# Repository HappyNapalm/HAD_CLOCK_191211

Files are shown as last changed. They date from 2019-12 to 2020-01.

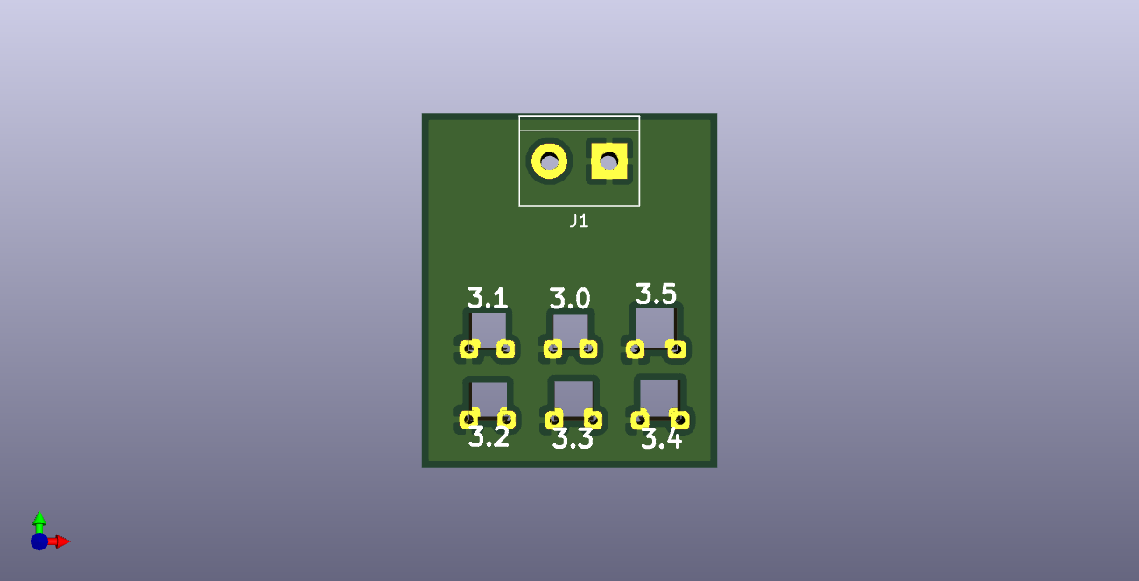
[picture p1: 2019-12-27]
renders/01_LED_test/rear.png

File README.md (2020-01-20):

# HAD_CLOCK_191211 #
Clock for HAD Contest

## TODO ##
* Final verification of footprints. Last time!
* Sort out transformer
* Design an enclosure
* Add buttons to program the time (Research cap touch)
* Convert Mouser Project into csv

~~Microcontroller Corrections to PIC18F45K20~~

~~Consider making a version for the LPC804 as well as the PIC~~

~~Consider making multiple sheets for the schematic~~

~~Redo the outline in 4 x 15 pattern instead of a 3 x 20 pattern~~

## Parts to Select ##
* Transformer
* Diodes
* Resist0r 0603 100 ohm for 20 mAs at 3v3. 72 resistors

~~Shift Register (Affects resistor size)~~

~~Full rectifier~~

## Brief License ##
* Non-comericial
* Unlimited remakes for personal use
* Cite this project as source for any re-mixes

### Online Resources ###
https://www.pcbway.com/pcb_prototype/What_are_Plated_Half_Holes_Castellated_Holes_.html

### KiCAD Renders ###

Front | Back
:-------:|:------:
![Clock Front] (https://github.com/HappyNapalm/HAD_CLOCK_191211/blob/pic18/front.png)  |  ![Clock Rear] (https://github.com/HappyNapalm/HAD_CLOCK_191211/blob/pic18/rear.png)

![LED Test Front] (../renders/01_LED_test/front.png)

![LED Test Rear] (../renders/01_LED_test/rear.png)

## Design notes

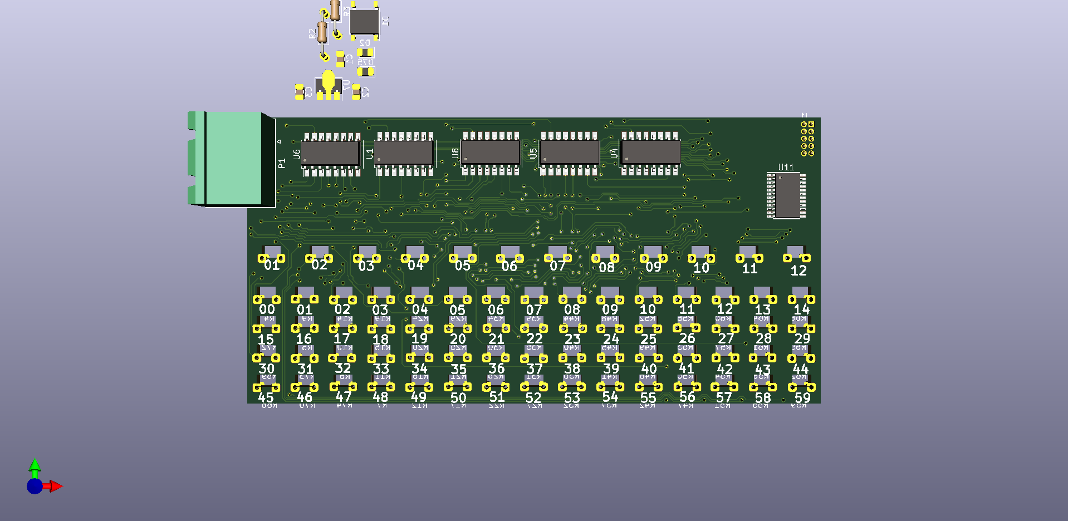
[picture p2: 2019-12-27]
front.png

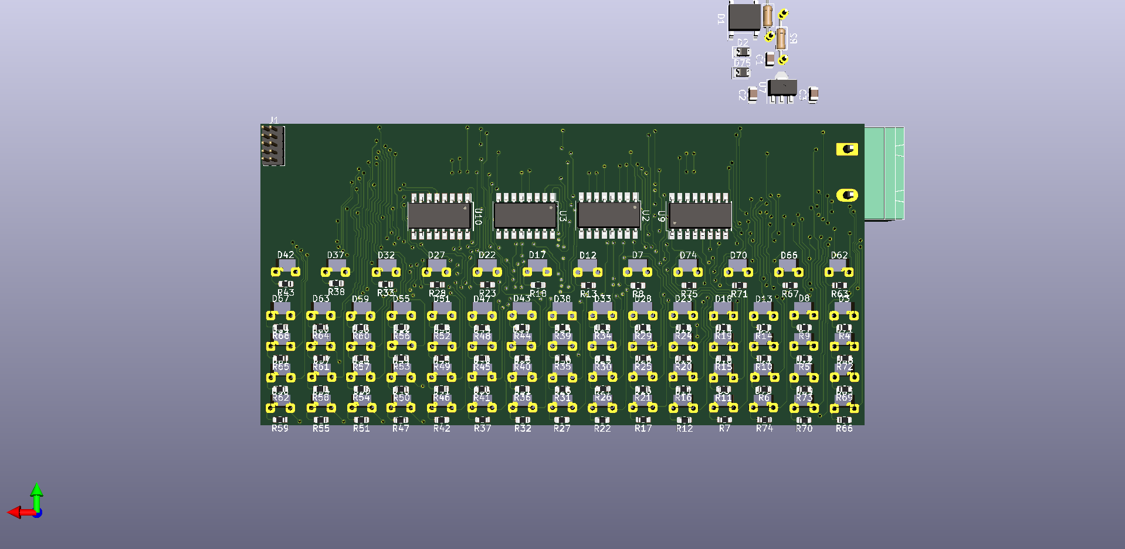
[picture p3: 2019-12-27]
rear.png

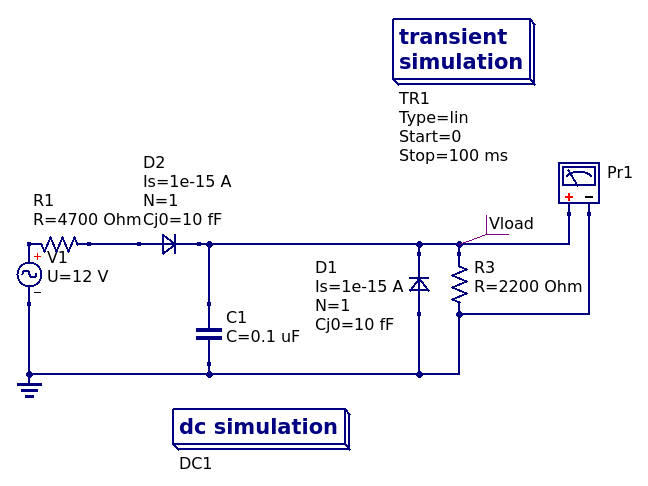
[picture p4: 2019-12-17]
Qucs Sims/sim_circuit.png

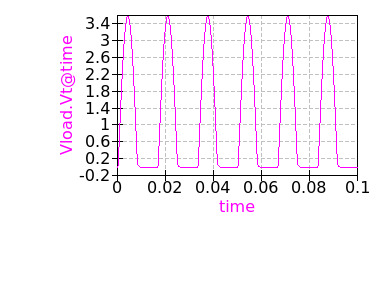
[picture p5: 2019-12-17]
Qucs Sims/sim_signal.png

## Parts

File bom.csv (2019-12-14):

Mouser PN | Description | Package | Quantity
771-NPIC6C596ADJ | Counter Shift Registers Power logic 8-bit. 596 Open Drain shift register | SO-16 | 9

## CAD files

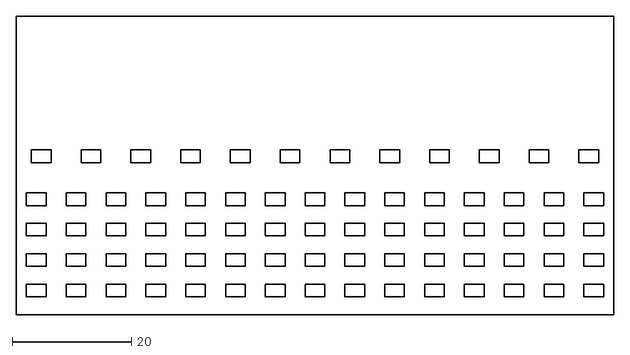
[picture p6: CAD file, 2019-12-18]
FreeCAD/clock_outline.dxf
100.0 x 50.0

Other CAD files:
FreeCAD/LED_hole_test.FCStd
FreeCAD/Clock_idea_outline.FCStd
FreeCAD/LED_hole_test.dxf

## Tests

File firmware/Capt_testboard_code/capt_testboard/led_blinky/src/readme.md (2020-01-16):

## Overview
-----------------------------------------------------------------------------------------
The LED Blinky demo application provides a sanity check for the new SDK build environments 
and board bring up. The LED Blinky demo uses the systick interrupt to realize the function 
of timing delay. The demo takes turns to shine the LED. The purpose of this demo is to 
provide a simple project for debugging and further development.

## Functional Description
-----------------------------------------------------------------------------------------
The LED Blinky demo mainly is to bring up the new SDK build environments on the board.
This demo will initialize the pin configuration, then configure System Tick to generate 
1ms interrupt. When 1000 interrupts occur(1s), the pin output of LED is toggled. We can 
see that LED is blinking on the board.

## Toolchain Supported
---------------------
- IAR embedded Workbench 8.22.1
- Keil MDK 5.24a
- MCUXpresso10.2.0

## Hardware Requirements
------------------------
- Mini/micro USB cable
- LPCXpresso804 board
- Personal Computer

## Board Settings
------------------------
No special settings are required.

## Run the Demo
------------------------
1. Connect a micro USB cable between the PC host and the CMSIS DAP port(CN2 on the board).

2. Choose an IDE, building the project and download the program to the target board.
   More information about how to compile and program the project can refer to the 

   [Getting Started with MCUXpresso SDK](../../../../docs/Getting Started with MCUXpresso SDK.pdf).

3. Launch the debugger in your IDE to begin running the demo.

## Expected Result
------------------------
When the demo runs successfully, you will find the LED is blinking.

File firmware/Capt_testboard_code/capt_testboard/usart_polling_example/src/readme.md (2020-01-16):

## Overview
-----------
This example demonstrates configuration and use of the USART module in polling-driven 
asynchronous mode on communication with a terminal emulator calling the USART functional
APIs. USART will echo back every 8 characters to terminal emulator.

**Transactional API and Functional API**

- Low level functional APIs provide common peripheral functionality, abstracting the 
  hardware peripheral register access into a set of state less basic functional operations.
  These APIs primarily focus on the control, configuration, and function of basic 
  peripheral operations. 

- Transactional APIs provide a quick method for customers to utilize higher-level 
  functionality of the peripherals. The transactional APIs utilize interrupts and perform 
  asynchronous operations without user intervention. Transactional APIs operate on high-
  level logic that requires data storage for internal operation context handling. However,
  the peripheral drivers do not allocate this memory space. Rather, the user passes in the
  memory to the driver for internal driver operation. 

- All driver examples calling the transactional API get the `transfer` in the project 
  naming. If the code size and performance are critical requirements, see the 
  transactional API implementation and write custom code.

## Functional Description
-------------------------
In this example, USART communicates with a terminal emulator running on the PC, via 
the VCOM serial port. 

When start running this example, main routine will initialize clock, pin mux configuration,
and configure the USART module to make it work in polling way. Users are prompted to 
input several characters, board will echo back the received characters to the terminal
immediately. 

## Toolchain Supported
---------------------
- IAR embedded Workbench 8.22.1
- Keil MDK 5.24a
- MCUXpresso10.2.0

## Hardware Requirements
------------------------
- Micro USB cable
- LPCXpresso804 board
- Personal Computer

## Board Settings
------------------------
No special settings are required.

## Run the Project
------------------------
Run the example by performing the following steps:

1. Connect a micro USB cable between the PC host and the CMSIS DAP port(CN2 on the 
   LPCXpresso804 board).

2. Open a serial terminal in PC(for example PUTTY) with the following settings:
   - 9600 baud rate
   - 8 data bits
   - No parity
   - One stop bit
   - No flow control

3. Compile and download the program to the target board.
   More information about how to compile and program the project can refer to 

   [Getting Started with MCUXpresso SDK](../../../../../docs/Getting Started with MCUXpresso SDK.pdf).

4. Launch the debugger in your IDE to begin running the project.

5. Input several characters according to prompt information displayed in terminal. 

## Expected Result
------------------------
Users are prompted to input several characters at the terminal emulator on PC, the input
character will be echoed back in the terminal immediately. Users will see what they have 
typed in the terminal.

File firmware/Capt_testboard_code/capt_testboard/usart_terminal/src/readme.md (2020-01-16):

## Overview
-----------
This example demonstrates configuration and use of the USART module in interrupt-driven 
asynchronous mode on communication with a terminal emulator calling the USART functional
APIs. USART will echo back every character to terminal emulator, and send back all 
received characters once users press `Enter`key.

**Transactional API and Functional API**

- Low level functional APIs provide common peripheral functionality, abstracting the 
  hardware peripheral register access into a set of state less basic functional operations.
  These APIs primarily focus on the control, configuration, and function of basic 
  peripheral operations. 

- Transactional APIs provide a quick method for customers to utilize higher-level 
  functionality of the peripherals. The transactional APIs utilize interrupts and perform 
  asynchronous operations without user intervention. Transactional APIs operate on high-
  level logic that requires data storage for internal operation context handling. However,
  the peripheral drivers do not allocate this memory space. Rather, the user passes in the
  memory to the driver for internal driver operation. 

- All driver examples calling the transactional API get the `transfer` in the project 
  naming. If the code size and performance are critical requirements, see the 
  transactional API implementation and write custom code.

## Functional Description
-------------------------
In this example, USART communicates with a terminal emulator running on the PC, via 
the VCOM serial port. 

1. Once the project start, main routine will initialize clock, pin mux configuration, 
   and configure the USART module to make it work in interrupt mode.
 
2. In the terminal on PC, user is prompted to input several characters and terminated 
   with `Enter` key. 

3. The USART IRQ handler will monitor the received data from the USART Rx(terminal) and 
   send back the same characters to terminal. IRQ Handler save the received characters 
   to the Rx buffer and check whether a `Enter` character is detected. If `Enter` is 
   detected, a flag `rxNewLineDetected` is set indicating a complete information is 
   received. 
   
4. The Main routine continuous checking the flag of `rxNewLineDetected` to decide whether
   to send the full string of the received inforamtion back to terminal. If yes, the 
   information will be sent back to terminal in interrupt-mode. USART IRQ handler will 
   check each IRQ triggered by USART transmit ready and fill the left data into the USART
   send register until all characters are sent. 

5. Main routinue repeats the check of the flag and send the received information to terminal. 

## Toolchain Supported
---------------------
- IAR embedded Workbench 8.22.1
- Keil MDK 5.24a
- MCUXpresso10.2.0

## Hardware Requirements
------------------------
- Micro USB cable
- LPCXpresso804 board
- Personal Computer

## Board Settings
------------------------
No special settings are required.

## Run the Project
------------------------
Run the USART terminal Example application by performing the following steps:

1. Connect a micro USB cable between the PC host and the CMSIS DAP port(CN2 on the 
   LPCXpresso804 board).

2. Open a serial terminal in PC(for example PUTTY) with the following settings:
   - 9600 baud rate
   - 8 data bits
   - No parity
   - One stop bit
   - No flow control

3. Compile and download the program to the target board.
   More information about how to compile and program the project can refer to 

   [Getting Started with MCUXpresso SDK](../../../../../docs/Getting Started with MCUXpresso SDK.pdf).

4. Launch the debugger in your IDE to begin running the project.

5. Input several characters followed with `Enter` key in terminal according to prompt
   information displayed in terminal. Repeat the step 5.

## Expected Result
------------------------
The input character will be direclty echoed back in the terminal. You will see what you have
typed in the terminal. When the `Enter` is input, the whole string will be echoed back to
the terminal.

***Note:*** The size of receive buffer is 32 bytes. Do not type characters more than 32 
beteween 2 `Enter`. If not, an notification of overflowed Rx buffer will be displayed in 
terminal and only the first 32 characters will be displayed.

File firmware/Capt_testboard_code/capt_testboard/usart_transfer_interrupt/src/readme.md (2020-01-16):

## Overview
--------------------------------------------------------------------------------------
This example demonstrate configuration and use of the USART module in interrupt-driven 
asynchronous mode on communication with a terminal emulator calling the USART 
transactional APIs. USART will echo back every 8 characters.

**Transactional API and Functional API**

- Low level functional APIs provide common peripheral functionality, abstracting the 
  hardware peripheral register access into a set of state less basic functional operations.
  These APIs primarily focus on the control, configuration, and function of basic 
  peripheral operations. 

- Transactional APIs provide a quick method for customers to utilize higher-level 
  functionality of the peripherals. The transactional APIs utilize interrupts and perform 
  asynchronous operations without user intervention. Transactional APIs operate on high-
  level logic that requires data storage for internal operation context handling. However,
  the peripheral drivers do not allocate this memory space. Rather, the user passes in the
  memory to the driver for internal driver operation. 

- All driver examples calling the transactional API get the `transfer` in the project 
  naming. If the code size and performance are critical requirements, see the 
  transactional API implementation and write custom code.

**Double weak mechanism used for transactional APIs **

- A double weak mechanism is introduced for drivers with transactional API. The double 
  weak indicates two levels of weak vector entries. See the examples below: 

```assembly
        PUBWEAK USART0_IRQHandler
        PUBWEAK USART0_DriverIRQHandler
USART0_IRQHandler
        LDR     R0, =USART0_DriverIRQHandler
        BX      R0
```

- The first level of the weak implementation are the functions defined in the vector 
  table. The drivers with transactional APIs provide the reimplementation of the second
  layer function inside of the peripheral driver. If the drivers with transactional APIs 
  are linked into the image, the `USART0_DriverIRQHandler` is replaced with the function
  implemented in the  USART driver. 

- The reason for implementing the double weak functions is to provide a better user 
  experience when using the transactional APIs. For drivers with a transactional function,
  call the transactional APIs and the drivers complete the interrupt-driven flow. Users are
  not required to redefine the vector entries out of the box. At the same time, if users 
  are not satisfied by the second layer weak function implemented in the drivers, users 
  can redefine the first layer weak function and implement their own interrupt handler 
  functions to suit their implementation.

## Functional description
---------------------------------------------------------------------------------------
In this example, USART communicates with a terminal emulator running on the PC, via 
the VCOM serial port. 

1. When users start running this project, main routine will initialize clock, pin mux 
   configuration, and configure the USART module to make it work in interrupt transactional
   mode.

2. In the terminal emulator running on PC, some information will be displayed to prompt
   users input 8 characters.
   
3. Once users entered 8 characters, main routine will echo back the received characters 
   to the terminal emulator and start for another loop transfer.
   
4. All read and write operations are executed in the interrupt handler(located in the 
   "fsl_usart.c" file) which is implemented in double weak mechanism, and the user does 
   not need to do other operations. But user can monitor the transmission state through
   the parameter `g_usartHandle`.

## Toolchain Supported
---------------------
- IAR embedded Workbench 8.22.1
- Keil MDK 5.24a
- MCUXpresso10.2.0

## Hardware Requirements
------------------------
- Mini/micro USB cable
- LPCXpresso804 board
- Personal Computer

## Board Settings
------------------------
No special settings are required.

## Run the Project
------------------------
Run the USART interrupt transfer example application by performing the following steps:

1. Connect a micro USB cable between the PC host and the CMSIS DAP port(CN2 on the 
   LPCXpresso804 board).

2. Open a serial terminal emulator(for example PUTTY) in PC with the following settings:
   - 9600 baud rate
   - 8 data bits
   - No parity
   - One stop bit
   - No flow control

3. Compile and download the program to the target board.
   More information about how to compile and program the project can refer to 

   [Getting Started with MCUXpresso SDK](../../../../../docs/Getting Started with MCUXpresso SDK.pdf).

4. Launch the debugger in your IDE to begin running the project.

5. Input several characters according to the prompt information displayed in terminal.
   Repeat the step 5.

## Expected Result
------------------------
Users are prompted to enter 8 characters according to the information displayed in the 
terminal emulator running on PC. Once the entered characters reach 8, board will echo back 
the received characters to the terminal emulator.
***Note:*** Board will not immediately return each character to terminal emulator until
all 8 characters are all entered

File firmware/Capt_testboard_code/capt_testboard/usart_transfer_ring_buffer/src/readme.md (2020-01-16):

## Overview
-----------
This example demonstrates the use of the USART module in interrupt-driven asynchronous
mode on communication with a terminal emulator calling the USART functional APIs with 
ring buffer used. USART will echo back every 8 characters to terminal emulator.

**Transactional API and Functional API**

- Low level functional APIs provide common peripheral functionality, abstracting the 
  hardware peripheral register access into a set of state less basic functional operations.
  These APIs primarily focus on the control, configuration, and function of basic 
  peripheral operations. 

- Transactional APIs provide a quick method for customers to utilize higher-level 
  functionality of the peripherals. The transactional APIs utilize interrupts and perform 
  asynchronous operations without user intervention. Transactional APIs operate on high-
  level logic that requires data storage for internal operation context handling. However,
  the peripheral drivers do not allocate this memory space. Rather, the user passes in the
  memory to the driver for internal driver operation. 

- All driver examples calling the transactional API get the `transfer` in the project 
  naming. If the code size and performance are critical requirements, see the 
  transactional API implementation and write custom code.

**Double weak mechanism used for transactional APIs **

- A double weak mechanism is introduced for drivers with transactional API. The double 
  weak indicates two levels of weak vector entries. See the examples below: 

```assembly
        PUBWEAK USART0_IRQHandler
        PUBWEAK USART0_DriverIRQHandler
USART0_IRQHandler
        LDR     R0, =USART0_DriverIRQHandler
        BX      R0
```

- The first level of the weak implementation are the functions defined in the vector 
  table. The drivers with transactional APIs provide the reimplementation of the second
  layer function inside of the peripheral driver. If the drivers with transactional APIs 
  are linked into the image, the `USART0_DriverIRQHandler` is replaced with the function
  implemented in the  USART driver. 

- The reason for implementing the double weak functions is to provide a better user 
  experience when using the transactional APIs. For drivers with a transactional function,
  call the transactional APIs and the drivers complete the interrupt-driven flow. Users are
  not required to redefine the vector entries out of the box. At the same time, if users 
  are not satisfied by the second layer weak function implemented in the drivers, users 
  can redefine the first layer weak function and implement their own interrupt handler 
  functions to suit their implementation.

## Functional Description
-------------------------
In this example, USART communicates with a terminal emulator running on the PC, via 
the VCOM serial port. 

1. When users start running this project, main routine will initialize clock, pin mux 
   configuration, configure the USART module, and start the ring buffer to make it work
   in interrupt transactional mode.

2. In the terminal emulator running on PC, some information will be displayed to prompt
   users input 8 characters.
   
3. Once users entered 8 characters, main routine will echo back the received characters 
   to the terminal emulator and start for another loop transfer.
   
4. All read and write operations are executed in the interrupt handler(located in the 
   "fsl_usart.c" file) which is implemented in double weak mechanism, and the user does 
   not need to do other operations. But user can monitor the transmission state through
   the parameter `g_usartHandle`.
   
5. In the case with ring buffer used, characters will be saved to the ring buffer if user
   has not called the receive non-blocking API. Once the receive non-blocking API was 
   called, main routine will continue receive data in interrupt-driven mode after checking
   the ring buffer if the data in ring buffer can't satisfy the receive size.   

## Toolchain Supported
---------------------
- IAR embedded Workbench 8.22.1
- Keil MDK 5.24a
- MCUXpresso10.2.0

## Hardware Requirements
------------------------
- Micro USB cable
- LPCXpresso804 board
- Personal Computer

## Board Settings
------------------------
No special settings are required.

## Run the Project
------------------------
Run the example by performing the following steps:

1. Connect a micro USB cable between the PC host and the CMSIS DAP port(CN2 on the 
   LPCXpresso804 board).

2. Open a serial terminal in PC(for example PUTTY) with the following settings:
   - 9600 baud rate
   - 8 data bits
   - No parity
   - One stop bit
   - No flow control

3. Compile and download the program to the target board.
   More information about how to compile and program the project can refer to 

   [Getting Started with MCUXpresso SDK](../../../../../docs/Getting Started with MCUXpresso SDK.pdf).

4. Launch the debugger in your IDE to begin running the project.

5. Input 8 characters every time according to the prompt information displayed in terminal.
   Repeat the step 5.

## Expected Result
------------------------
Users are prompted to enter 8 characters according to the information displayed in the 
terminal emulator running on PC. Once the entered characters reach 8, board will echo back 
the received characters to the terminal emulator.

***Note:*** Board will not immediately return each character to terminal emulator until
all 8 characters are all entered

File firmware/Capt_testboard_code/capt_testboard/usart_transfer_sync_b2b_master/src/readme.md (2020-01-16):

## Overview
-----------
This example demonstrates configuration and use of the USART module in synchronous mode.
Master will send data to slave on one board, 

**Transactional API and Functional API**

- Low level functional APIs provide common peripheral functionality, abstracting the 
  hardware peripheral register access into a set of state less basic functional operations.
  These APIs primarily focus on the control, configuration, and function of basic 
  peripheral operations. 

- Transactional APIs provide a quick method for customers to utilize higher-level 
  functionality of the peripherals. The transactional APIs utilize interrupts and perform 
  asynchronous operations without user intervention. Transactional APIs operate on high-
  level logic that requires data storage for internal operation context handling. However,
  the peripheral drivers do not allocate this memory space. Rather, the user passes in the
  memory to the driver for internal driver operation. 

- All driver examples calling the transactional API get the `transfer` in the project 
  naming. If the code size and performance are critical requirements, see the 
  transactional API implementation and write custom code.

**Double weak mechanism used for transactional APIs **

- A double weak mechanism is introduced for drivers with transactional API. The double 
  weak indicates two levels of weak vector entries. See the examples below: 

```assembly
        PUBWEAK USART0_IRQHandler
        PUBWEAK USART0_DriverIRQHandler
USART0_IRQHandler
        LDR     R0, =USART0_DriverIRQHandler
        BX      R0
```

- The first level of the weak implementation are the functions defined in the vector 
  table. The drivers with transactional APIs provide the reimplementation of the second
  layer function inside of the peripheral driver. If the drivers with transactional APIs 
  are linked into the image, the `USART0_DriverIRQHandler` is replaced with the function
  implemented in the  USART driver. 

- The reason for implementing the double weak functions is to provide a better user 
  experience when using the transactional APIs. For drivers with a transactional function,
  call the transactional APIs and the drivers complete the interrupt-driven flow. Users are
  not required to redefine the vector entries out of the box. At the same time, if users 
  are not satisfied by the second layer weak function implemented in the drivers, users 
  can redefine the first layer weak function and implement their own interrupt handler 
  functions to suit their implementation.

## Functional Description
-------------------------
In this example, USART will send data to slave on one board, the project inforamtion will
be displayed in the terminal emulator running on PC.

1. Once the project start, main routine will initialize clock, pin mux configuration, 
   and configure one USART module as master and another USART module as slave.
 
2. A transactional API will be used for slave instance to receive data from master instance
   which is in polling-driven mode, once the transmission is complete, the inforamtion will 
   be print out to terminal emulator telling users if this transmission is success.

3. The slave is in interrupt-driven mode, all read and write operations are executed in the 
   interrupt handler(located in the "fsl_usart.c" file) which is implemented in double weak
   mechanism, and the user does not need to do other operations. 
   
4. De-initialize the USART instances after the transmission is complete.

## Toolchain Supported
---------------------
- IAR embedded Workbench 8.22.1
- Keil MDK 5.24a
- MCUXpresso10.2.0

## Hardware Requirements
------------------------
- Micro USB cable
- LPCXpresso804 board
- Personal Computer

## Board Settings
------------------------
Please connect the USART1_CLK pin to USART1_CLK pin directly.
No need to connect other pins, because the data pins of USART master and slave are multiple
used. Just connect the pins like below:

Master - USART1                Slave - USART1   
Pin Name   Board Location      Pin Name   Board Location            
TXD       CN3 pin 10           RXD       CN3 pin 9                   
RXD       CN3 pin 9            TXD       CN3 pin 10               
SCK       CN8 pin 2            SCK       CN8 pin 2   

## Run the Project
------------------------
Run the example by performing the following steps:

1. Connect a micro USB cable between the PC host and the CMSIS DAP port(CN2 on the 
   LPCXpresso802 board), and make sure the board settings has been set up correctly.

2. Open a serial terminal in PC(for example PUTTY) with the following settings:
   - 9600 baud rate
   - 8 data bits
   - No parity
   - One stop bit
   - No flow control

3. Compile and download the program to the target board.
   More information about how to compile and program the project can refer to 

   [Getting Started with MCUXpresso SDK](../../../../../docs/Getting Started with MCUXpresso SDK.pdf).

4. Launch the debugger in your IDE to begin running the project.

5. Monitor the inforamtion displayed in the terminal emulator to check if the transmission 
   is success.

## Expected Result
------------------------
The debug console will print some information to the terminal emulator running on PC
to tell users if the transmission is success after the transmission between master and
slave is complete.

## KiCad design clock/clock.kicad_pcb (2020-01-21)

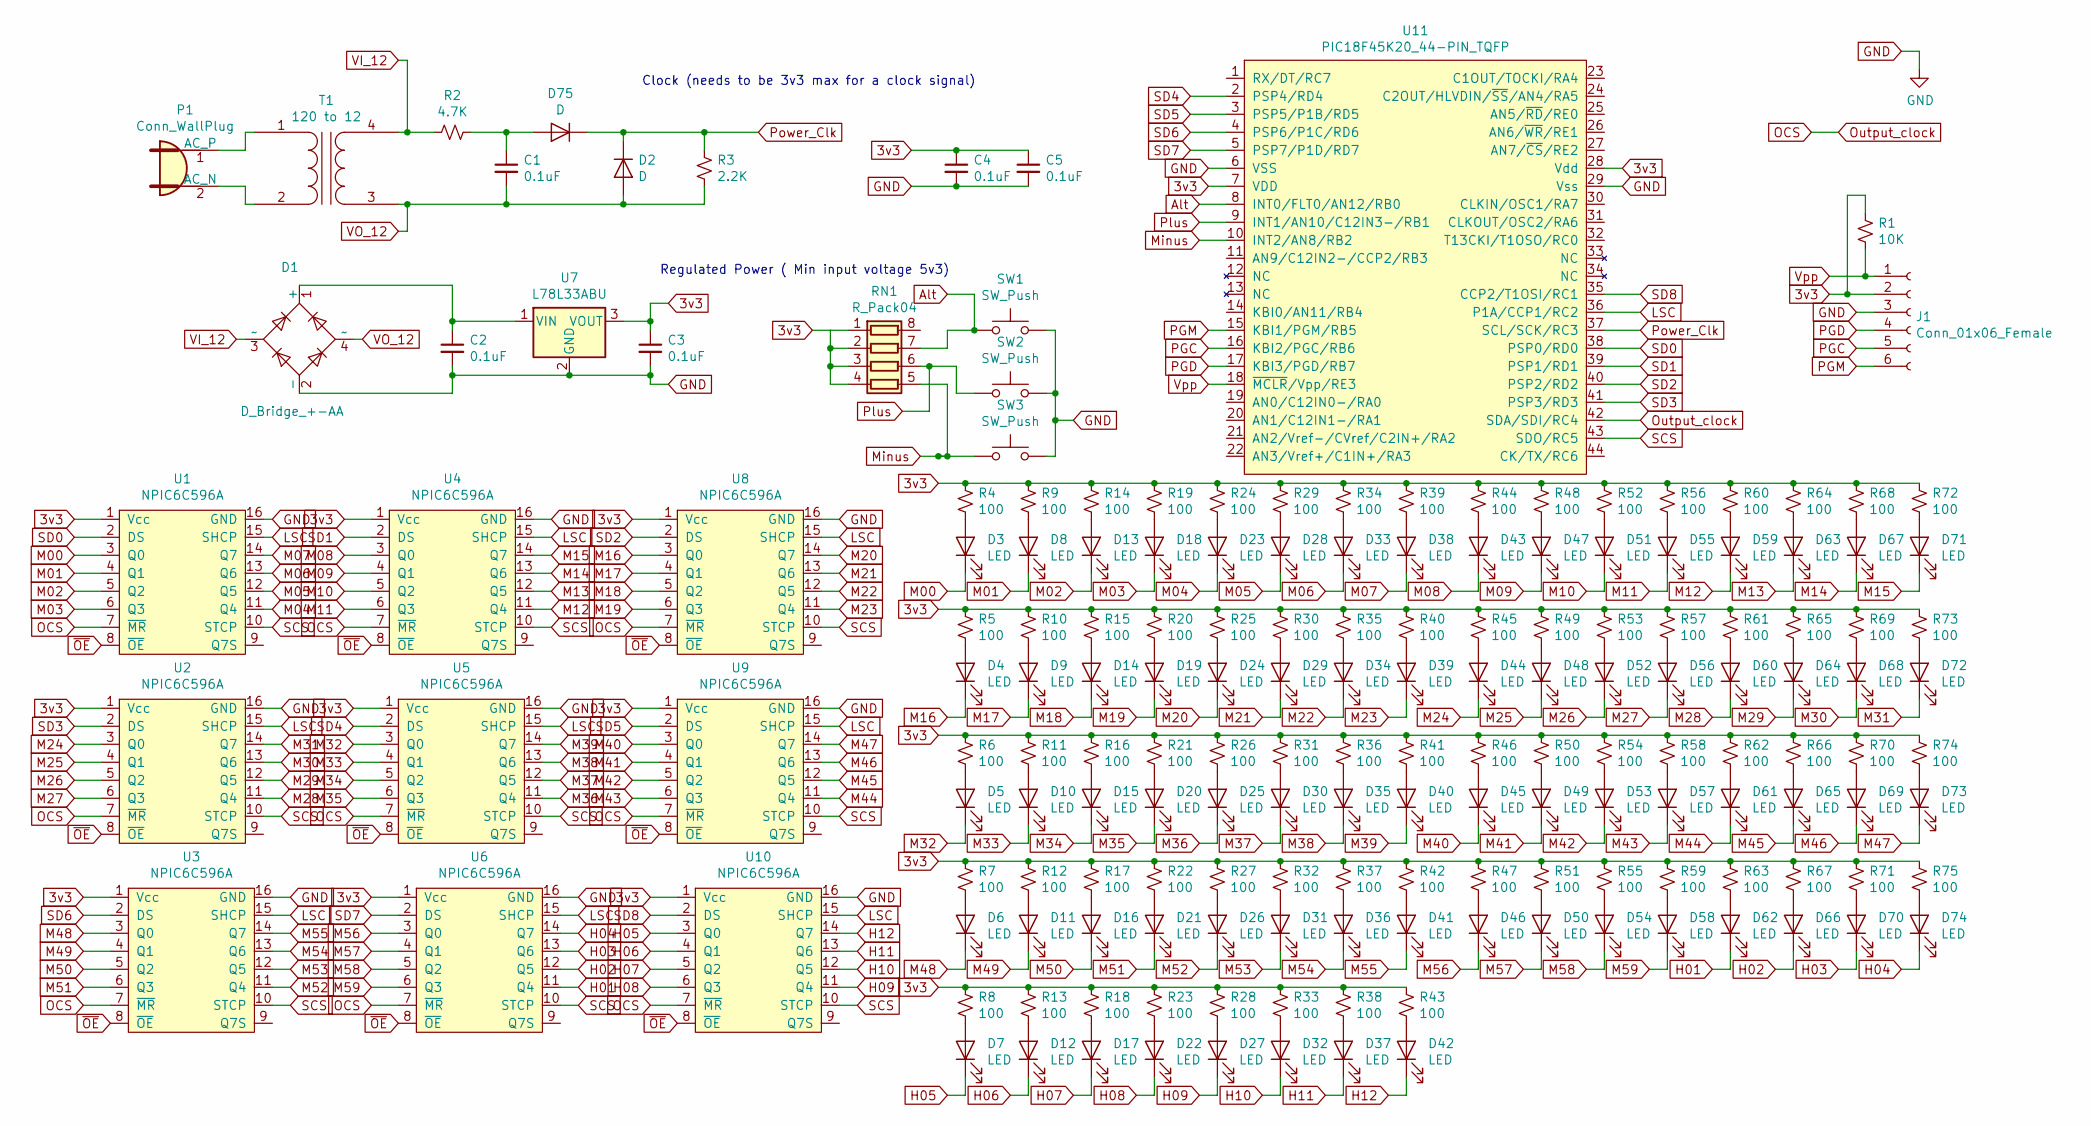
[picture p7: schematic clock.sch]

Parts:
C1, C2, C3, C4, C5: 0.1uF; C_0805_2012Metric
D1: D_Bridge_+-AA; Diode_Bridge_Diotec_ABS
D2, D75: D; D_0805_2012Metric
D3, D4, D5, D6, D7, D8, D9, D10, D11, D12, D13, D14, D15, D16, D17, D18, D19, D20, D21, D22, D23, D24, D25, D26, D27, D28, D29, D30, D31, D32, D33, D34, D35, D36, D37, D38, D39, D40, D41, D42, D43, D44, D45, D46, D47, D48, D49, D50, D51, D52, D53, D54, D55, D56, D57, D58, D59, D60, D61, D62, D63, D64, D65, D66, D67, D68, D69, D70, D71, D72, D73, D74: LED; LTST-S110KGKT_castellated_silkV1_rounded_rec
J1: Conn_01x06_Female; PinHeader_1x06_P2.54mm_Vertical
P1: Conn_WallPlug; PhoenixContact_GMSTBA_2,5_2-G-7,62_1x02_P7.62mm_Horizontal
R1: 10K; R_0805_2012Metric
R2: 4.7K; R_Axial_DIN0204_L3.6mm_D1.6mm_P7.62mm_Horizontal
R3: 2.2K; R_Axial_DIN0204_L3.6mm_D1.6mm_P7.62mm_Horizontal
R4, R5, R6, R7, R8, R9, R10, R11, R12, R13, R14, R15, R16, R17, R18, R19, R20, R21, R22, R23, R24, R25, R26, R27, R28, R29, R30, R31, R32, R33, R34, R35, R36, R37, R38, R39, R40, R41, R42, R43, R44, R45, R46, R47, R48, R49, R50, R51, R52, R53, R54, R55, R56, R57, R58, R59, R60, R61, R62, R63, R64, R65, R66, R67, R68, R69, R70, R71, R72, R73, R74, R75: 100; R_0603_1608Metric
RN1: R_Pack04; R_Array_Concave_4x0603
SW1, SW2, SW3: SW_Push; LL3301FF065QJ
T1: 120 to 12; TerminalBlock_bornier-2_P5.08mm
U1, U2, U3, U4, U5, U6, U8, U9, U10: NPIC6C596A; TSSOP-16_4.4x5mm_P0.65mm
U7: L78L33ABU; SOT-89-3
U11: PIC18F45K20_44-PIN_TQFP; TQFP-44_10x10mm_P0.8mm

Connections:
3v3: C3.1, C4.1, C5.1, J1.2, R1.1, R4.1, R5.1, R6.1, R7.1, R8.1, R9.1, R10.1, R11.1, R12.1, R13.1, R14.1, R15.1, R16.1, R17.1, R18.1, R19.1, R20.1, R21.1, R22.1, R23.1, R24.1, R25.1, R26.1, R27.1, R28.1, R29.1, R30.1, R31.1, R32.1, R33.1, R34.1, R35.1, R36.1, R37.1, R38.1, R39.1, R40.1, R41.1, R42.1, R43.1, R44.1, R45.1, R46.1, R47.1, R48.1, R49.1, R50.1, R51.1, R52.1, R53.1, R54.1, R55.1, R56.1, R57.1, R58.1, R59.1, R60.1, R61.1, R62.1, R63.1, R64.1, R65.1, R66.1, R67.1, R68.1, R69.1, R70.1, R71.1, R72.1, R73.1, R74.1, R75.1, RN1.1 (R1.1), RN1.2 (R2.1), RN1.3 (R3.1), RN1.4 (R4.1), U1.1 (Vcc), U2.1 (Vcc), U3.1 (Vcc), U4.1 (Vcc), U5.1 (Vcc), U6.1 (Vcc), U7.3 (VOUT), U8.1 (Vcc), U9.1 (Vcc), U10.1 (Vcc), U11.7 (VDD), U11.28 (Vdd)
Alt: RN1.7 (R2.2), SW1.1, U11.8 (INT0/FLT0/AN12/RB0)
GND: C2.2, C3.2, C4.2, C5.2, D1.2 (-), J1.3, SW1.2, SW2.2, SW3.2, U1.16 (GND), U2.16 (GND), U3.16 (GND), U4.16 (GND), U5.16 (GND), U6.16 (GND), U7.2 (GND), U8.16 (GND), U9.16 (GND), U10.16 (GND), U11.6 (VSS), U11.29 (Vss)
H01: D62.1 (K), U6.11 (Q4)
H02: D66.1 (K), U6.12 (Q5)
H03: D70.1 (K), U6.13 (Q6)
H04: D74.1 (K), U6.14 (Q7)
H05: D7.1 (K), U10.3 (Q0)
H06: D12.1 (K), U10.4 (Q1)
H07: D17.1 (K), U10.5 (Q2)
H08: D22.1 (K), U10.6 (Q3)
H09: D27.1 (K), U10.11 (Q4)
H10: D32.1 (K), U10.12 (Q5)
H11: D37.1 (K), U10.13 (Q6)
H12: D42.1 (K), U10.14 (Q7)
LSC: U1.15 (SHCP), U2.15 (SHCP), U3.15 (SHCP), U4.15 (SHCP), U5.15 (SHCP), U6.15 (SHCP), U8.15 (SHCP), U9.15 (SHCP), U10.15 (SHCP), U11.36 (P1A/CCP1/RC2)
M00: D3.1 (K), U1.3 (Q0)
M01: D8.1 (K), U1.4 (Q1)
M02: D13.1 (K), U1.5 (Q2)
M03: D18.1 (K), U1.6 (Q3)
M04: D23.1 (K), U1.11 (Q4)
M05: D28.1 (K), U1.12 (Q5)
M06: D33.1 (K), U1.13 (Q6)
M07: D38.1 (K), U1.14 (Q7)
M08: D43.1 (K), U4.3 (Q0)
M09: D47.1 (K), U4.4 (Q1)
M10: D51.1 (K), U4.5 (Q2)
M11: D55.1 (K), U4.6 (Q3)
M12: D59.1 (K), U4.11 (Q4)
M13: D63.1 (K), U4.12 (Q5)
M14: D67.1 (K), U4.13 (Q6)
M15: D71.1 (K), U4.14 (Q7)
M16: D4.1 (K), U8.3 (Q0)
M17: D9.1 (K), U8.4 (Q1)
M18: D14.1 (K), U8.5 (Q2)
M19: D19.1 (K), U8.6 (Q3)
M20: D24.1 (K), U8.14 (Q7)
M21: D29.1 (K), U8.13 (Q6)
M22: D34.1 (K), U8.12 (Q5)
M23: D39.1 (K), U8.11 (Q4)
M24: D44.1 (K), U2.3 (Q0)
M25: D48.1 (K), U2.4 (Q1)
M26: D52.1 (K), U2.5 (Q2)
M27: D56.1 (K), U2.6 (Q3)
M28: D60.1 (K), U2.11 (Q4)
M29: D64.1 (K), U2.12 (Q5)
M30: D68.1 (K), U2.13 (Q6)
M31: D72.1 (K), U2.14 (Q7)
M32: D5.1 (K), U5.3 (Q0)
M33: D10.1 (K), U5.4 (Q1)
M34: D15.1 (K), U5.5 (Q2)
M35: D20.1 (K), U5.6 (Q3)
M36: D25.1 (K), U5.11 (Q4)
M37: D30.1 (K), U5.12 (Q5)
M38: D35.1 (K), U5.13 (Q6)
M39: D40.1 (K), U5.14 (Q7)
M40: D45.1 (K), U9.3 (Q0)
M41: D49.1 (K), U9.4 (Q1)
M42: D53.1 (K), U9.5 (Q2)
M43: D57.1 (K), U9.6 (Q3)
M44: D61.1 (K), U9.11 (Q4)
M45: D65.1 (K), U9.12 (Q5)
M46: D69.1 (K), U9.13 (Q6)
M47: D73.1 (K), U9.14 (Q7)
M48: D6.1 (K), U3.3 (Q0)
M49: D11.1 (K), U3.4 (Q1)
M50: D16.1 (K), U3.5 (Q2)
M51: D21.1 (K), U3.6 (Q3)
M52: D26.1 (K), U3.11 (Q4)
M53: D31.1 (K), U3.12 (Q5)
M54: D36.1 (K), U3.13 (Q6)
M55: D41.1 (K), U3.14 (Q7)
M56: D46.1 (K), U6.3 (Q0)
M57: D50.1 (K), U6.4 (Q1)
M58: D54.1 (K), U6.5 (Q2)
M59: D58.1 (K), U6.6 (Q3)
Minus: RN1.5 (R4.2), SW3.1, U11.10 (INT2/AN8/RB2)
unnamed: C1.1, D75.2 (A), R2.1
unnamed: C2.1, D1.1 (+), U7.1 (VIN)
unnamed: D3.2 (A), R4.2
unnamed: D4.2 (A), R5.2
unnamed: D5.2 (A), R6.2
unnamed: D6.2 (A), R7.2
unnamed: D7.2 (A), R8.2
unnamed: D8.2 (A), R9.2
unnamed: D9.2 (A), R10.2
unnamed: D10.2 (A), R11.2
unnamed: D11.2 (A), R12.2
unnamed: D12.2 (A), R13.2
unnamed: D13.2 (A), R14.2
unnamed: D14.2 (A), R15.2
unnamed: D15.2 (A), R16.2
unnamed: D16.2 (A), R17.2
unnamed: D17.2 (A), R18.2
unnamed: D18.2 (A), R19.2
unnamed: D19.2 (A), R20.2
unnamed: D20.2 (A), R21.2
unnamed: D21.2 (A), R22.2
unnamed: D22.2 (A), R23.2
unnamed: D23.2 (A), R24.2
unnamed: D24.2 (A), R25.2
unnamed: D25.2 (A), R26.2
unnamed: D26.2 (A), R27.2
unnamed: D27.2 (A), R28.2
unnamed: D28.2 (A), R29.2
unnamed: D29.2 (A), R30.2
unnamed: D30.2 (A), R31.2
unnamed: D31.2 (A), R32.2
unnamed: D32.2 (A), R33.2
unnamed: D33.2 (A), R34.2
unnamed: D34.2 (A), R35.2
unnamed: D35.2 (A), R36.2
unnamed: D36.2 (A), R37.2
unnamed: D37.2 (A), R38.2
unnamed: D38.2 (A), R39.2
unnamed: D39.2 (A), R40.2
unnamed: D40.2 (A), R41.2
unnamed: D41.2 (A), R42.2
unnamed: D42.2 (A), R43.2
unnamed: D43.2 (A), R44.2
unnamed: D44.2 (A), R45.2
unnamed: D45.2 (A), R46.2
unnamed: D46.2 (A), R47.2
unnamed: D47.2 (A), R48.2
unnamed: D48.2 (A), R49.2
unnamed: D49.2 (A), R50.2
unnamed: D50.2 (A), R51.2
unnamed: D51.2 (A), R52.2
unnamed: D52.2 (A), R53.2
unnamed: D53.2 (A), R54.2
unnamed: D54.2 (A), R55.2
unnamed: D55.2 (A), R56.2
unnamed: D56.2 (A), R57.2
unnamed: D57.2 (A), R58.2
unnamed: D58.2 (A), R59.2
unnamed: D59.2 (A), R60.2
unnamed: D60.2 (A), R61.2
unnamed: D61.2 (A), R62.2
unnamed: D62.2 (A), R63.2
unnamed: D63.2 (A), R64.2
unnamed: D64.2 (A), R65.2
unnamed: D65.2 (A), R66.2
unnamed: D66.2 (A), R67.2
unnamed: D67.2 (A), R68.2
unnamed: D68.2 (A), R69.2
unnamed: D69.2 (A), R70.2
unnamed: D70.2 (A), R71.2
unnamed: D71.2 (A), R72.2
unnamed: D72.2 (A), R73.2
unnamed: D73.2 (A), R74.2
unnamed: D74.2 (A), R75.2
unnamed: P1.1 (AC_P), T1.1 (AA)
unnamed: P1.2 (AC_N), T1.2 (AB)
OCS: U1.7 (~MR), U2.7 (~MR), U3.7 (~MR), U4.7 (~MR), U5.7 (~MR), U6.7 (~MR), U8.7 (~MR), U9.7 (~MR), U10.7 (~MR), U11.42 (SDA/SDI/RC4)
PGC: J1.5, U11.16 (KBI2/PGC/RB6)
PGD: J1.4, U11.17 (KBI3/PGD/RB7)
PGM: J1.6, U11.15 (KBI1/PGM/RB5)
Plus: RN1.6 (R3.2), SW2.1, U11.9 (INT1/AN10/C12IN3-/RB1)
Power_Clk: D2.1 (K), D75.1 (K), R3.2, U11.37 (SCL/SCK/RC3)
SCS: U1.10 (STCP), U2.10 (STCP), U3.10 (STCP), U4.10 (STCP), U5.10 (STCP), U6.10 (STCP), U8.10 (STCP), U9.10 (STCP), U10.10 (STCP), U11.43 (SDO/RC5)
SD0: U1.2 (DS), U11.38 (PSP0/RD0)
SD1: U4.2 (DS), U11.39 (PSP1/RD1)
SD2: U8.2 (DS), U11.40 (PSP2/RD2)
SD3: U2.2 (DS), U11.41 (PSP3/RD3)
SD4: U5.2 (DS), U11.2 (PSP4/RD4)
SD5: U9.2 (DS), U11.3 (PSP5/P1B/RD5)
SD6: U3.2 (DS), U11.4 (PSP6/P1C/RD6)
SD7: U6.2 (DS), U11.5 (PSP7/P1D/RD7)
SD8: U10.2 (DS), U11.35 (CCP2/T1OSI/RC1)
VI_12: D1.3 (~~), R2.2, T1.4 (SB)
VO_12: C1.2, D1.4 (~~), D2.2 (A), R3.1, T1.3 (SA)
Vpp: J1.1, R1.2, U11.18 (~MCLR~/Vpp/RE3)
~OE: U1.8 (~OE), U2.8 (~OE), U3.8 (~OE), U4.8 (~OE), U5.8 (~OE), U6.8 (~OE), U8.8 (~OE), U9.8 (~OE), U10.8 (~OE)

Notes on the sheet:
Clock (needs to be 3v3 max for a clock signal)
Regulated Power ( Min input voltage 5v3)

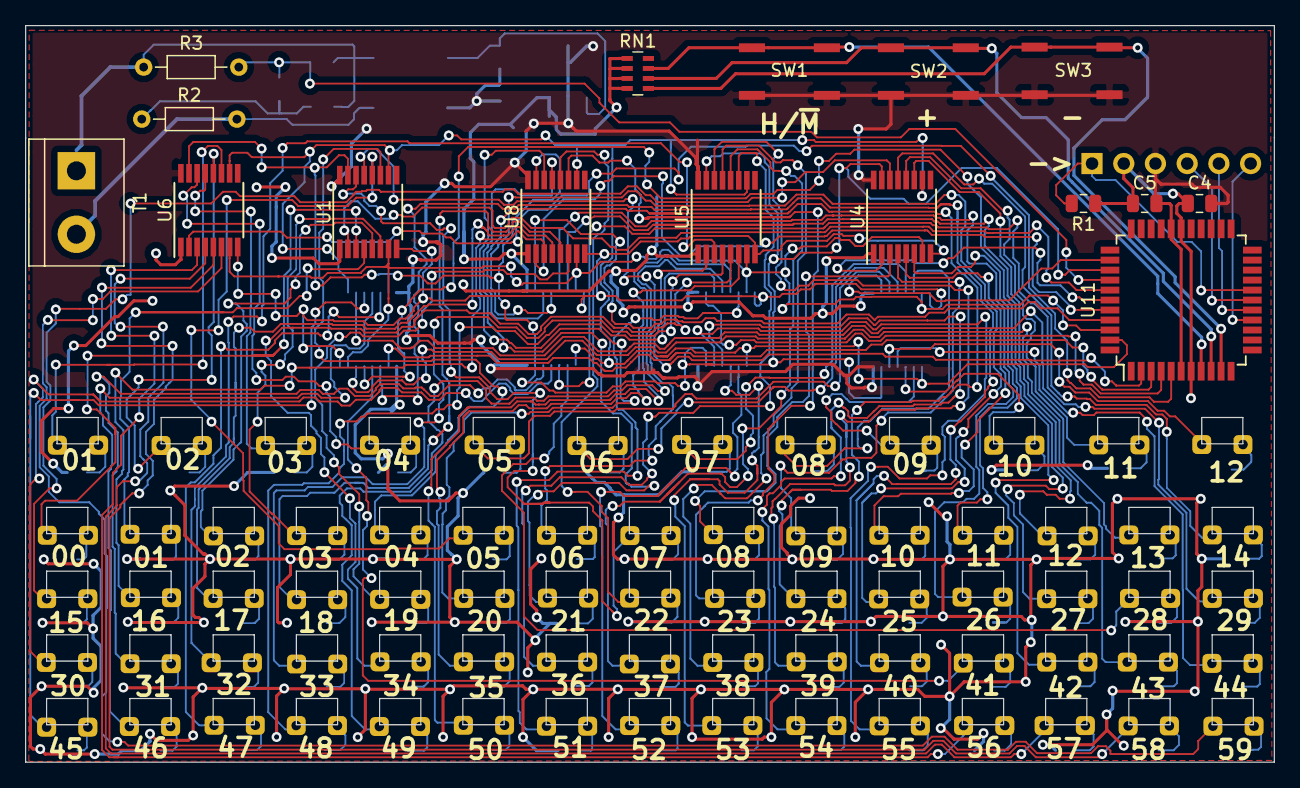
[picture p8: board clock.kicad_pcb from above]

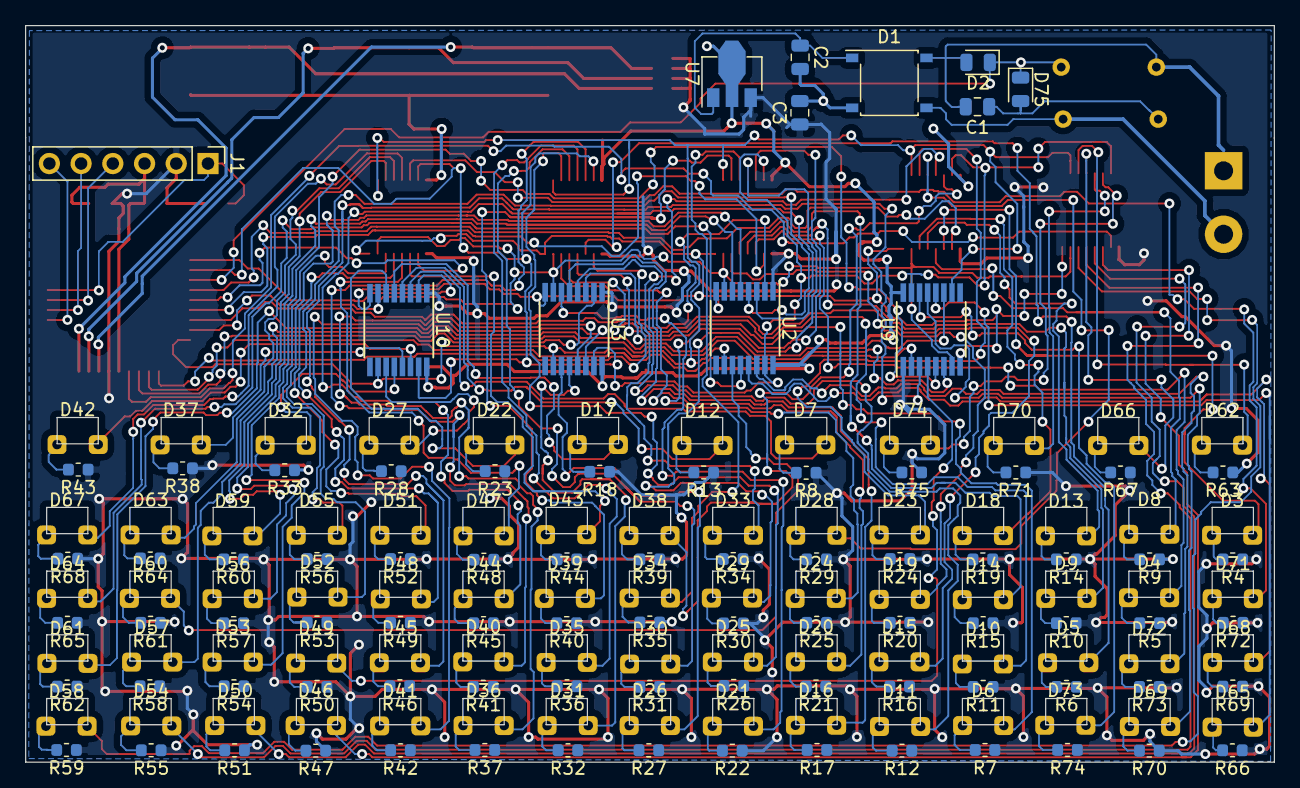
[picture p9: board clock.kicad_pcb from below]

Board: 2 copper layers, 100.0 x 59.0 mm, 172 parts (156 on the bottom side), 171 nets.

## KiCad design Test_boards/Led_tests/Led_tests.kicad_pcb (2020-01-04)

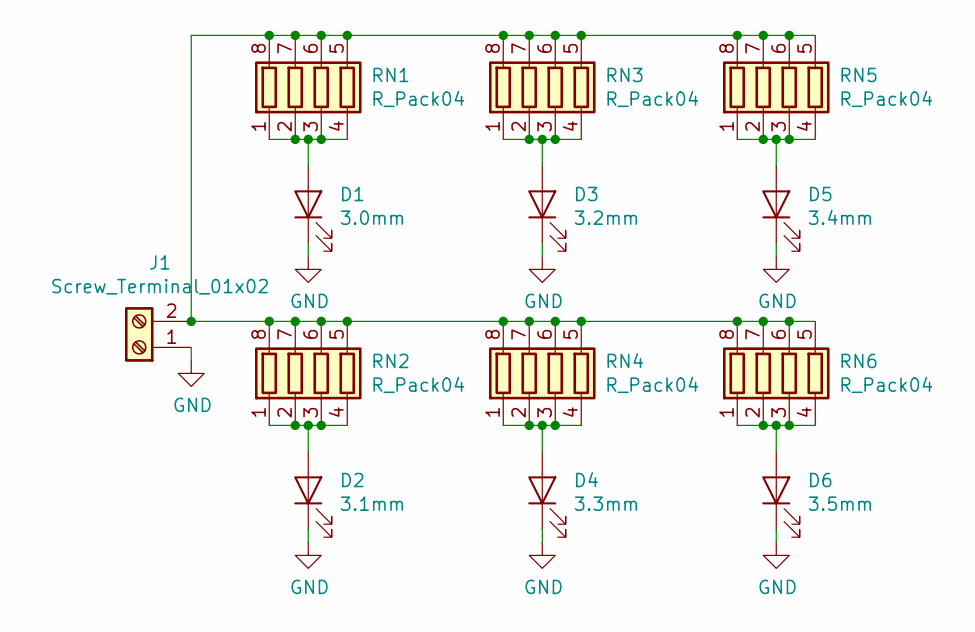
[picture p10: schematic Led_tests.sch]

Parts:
D1: 3.0mm; LTST-S110KGKT_castellated_3.0mm
D2: 3.1mm; LTST-S110KGKT_castellated_3.1mm
D3: 3.2mm; LTST-S110KGKT_castellated_3.2mm
D4: 3.3mm; LTST-S110KGKT_castellated_3.3mm
D5: 3.4mm; LTST-S110KGKT_castellated_3.4mm
D6: 3.5mm; LTST-S110KGKT_castellated_3.5mm
J1: Screw_Terminal_01x02; TerminalBlock_bornier-2_P5.08mm
RN1, RN2, RN3, RN4, RN5, RN6: R_Pack04; R_Array_Concave_4x0603

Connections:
GND: D1.1 (K), D2.1 (K), D3.1 (K), D4.1 (K), D5.1 (K), D6.1 (K), J1.1
unnamed: D1.2 (A), RN1.1 (R1.1), RN1.2 (R2.1), RN1.3 (R3.1), RN1.4 (R4.1)
unnamed: D2.2 (A), RN2.1 (R1.1), RN2.2 (R2.1), RN2.3 (R3.1), RN2.4 (R4.1)
unnamed: D3.2 (A), RN3.1 (R1.1), RN3.2 (R2.1), RN3.3 (R3.1), RN3.4 (R4.1)
unnamed: D4.2 (A), RN4.1 (R1.1), RN4.2 (R2.1), RN4.3 (R3.1), RN4.4 (R4.1)
unnamed: D5.2 (A), RN5.1 (R1.1), RN5.2 (R2.1), RN5.3 (R3.1), RN5.4 (R4.1)
unnamed: D6.2 (A), RN6.1 (R1.1), RN6.2 (R2.1), RN6.3 (R3.1), RN6.4 (R4.1)
unnamed: J1.2, RN1.5 (R4.2), RN1.6 (R3.2), RN1.7 (R2.2), RN1.8 (R1.2), RN2.5 (R4.2), RN2.6 (R3.2), RN2.7 (R2.2), RN2.8 (R1.2), RN3.5 (R4.2), RN3.6 (R3.2), RN3.7 (R2.2), RN3.8 (R1.2), RN4.5 (R4.2), RN4.6 (R3.2), RN4.7 (R2.2), RN4.8 (R1.2), RN5.5 (R4.2), RN5.6 (R3.2), RN5.7 (R2.2), RN5.8 (R1.2), RN6.5 (R4.2), RN6.6 (R3.2), RN6.7 (R2.2), RN6.8 (R1.2)

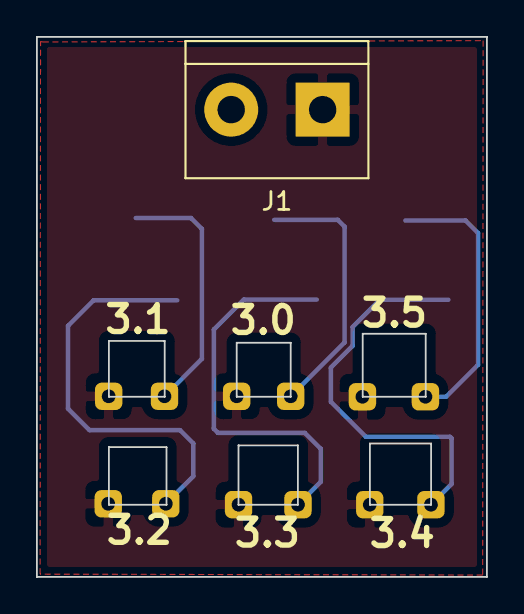
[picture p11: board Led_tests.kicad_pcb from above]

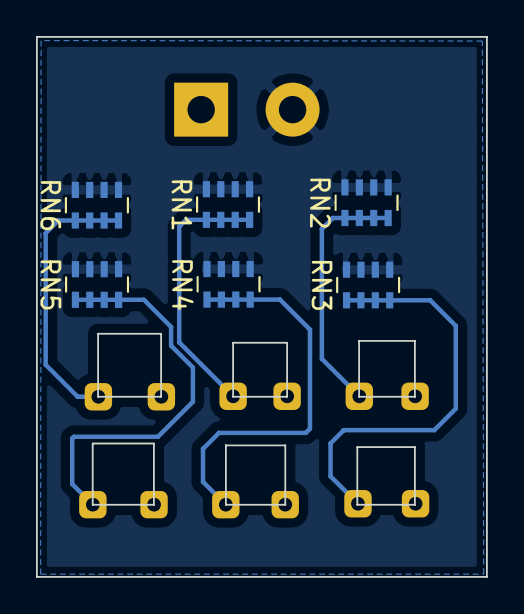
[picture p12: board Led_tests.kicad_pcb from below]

Board: 2 copper layers, 25.0 x 30.0 mm, 13 parts (6 on the bottom side), 8 nets.

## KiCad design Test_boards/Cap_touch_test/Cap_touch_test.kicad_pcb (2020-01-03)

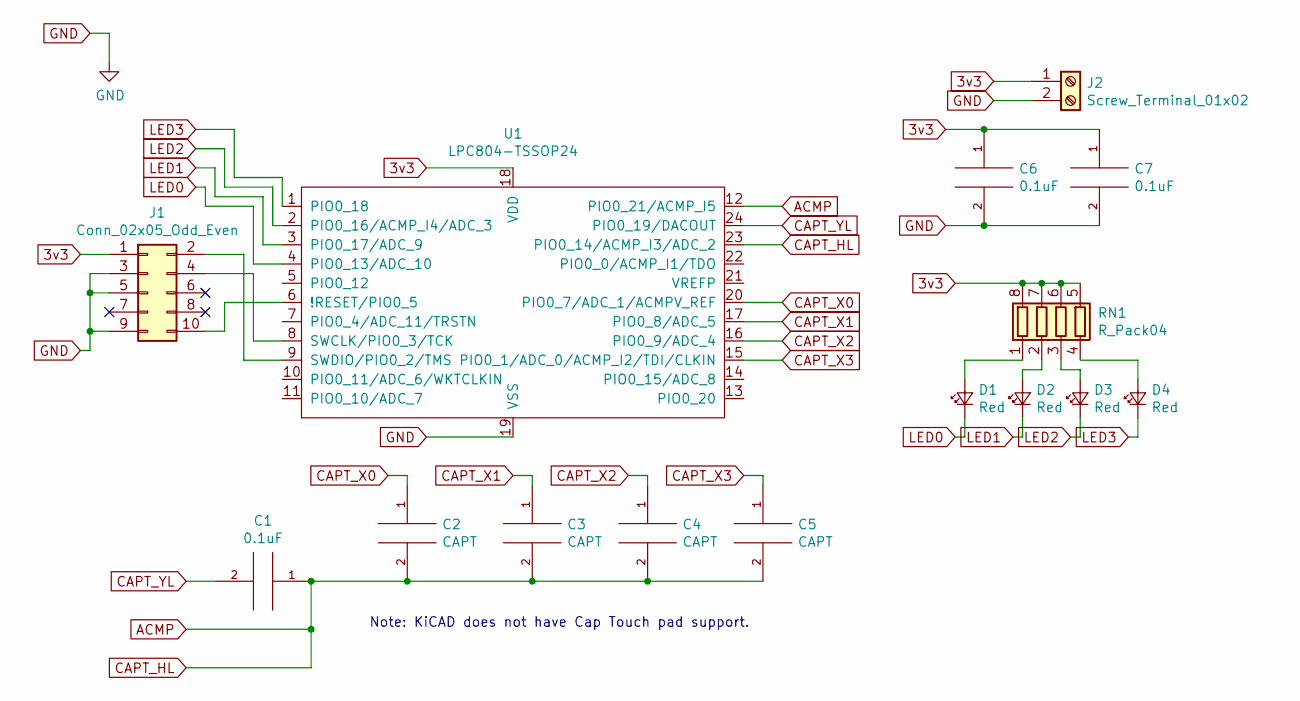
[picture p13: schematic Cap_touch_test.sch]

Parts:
C1, C6, C7: 0.1uF; C_0805_2012Metric
C2, C3, C4, C5: CAPT; Cap_T_pad_v1.1
D1, D2, D3, D4: Red; D_0805_2012Metric
J1: Conn_02x05_Odd_Even; PinHeader_2x05_P1.27mm_Vertical
J2: Screw_Terminal_01x02; TerminalBlock_bornier-2_P5.08mm
RN1: R_Pack04; R_Array_Concave_4x0603
U1: LPC804-TSSOP24; TSSOP-24_4.4x7.8mm_P0.65mm

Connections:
3v3: C6.1, C7.1, J1.1, J2.1, RN1.5 (R4.2), RN1.6 (R3.2), RN1.7 (R2.2), RN1.8 (R1.2), U1.18 (VDD)
ACMP: C1.1, C2.2, C3.2, C4.2, C5.2, U1.12 (PIO0_21/ACMP_I5), U1.23 (PIO0_14/ACMP_I3/ADC_2)
CAPT_X0: C2.1, U1.20 (PIO0_7/ADC_1/ACMPV_REF)
CAPT_X1: C3.1, U1.17 (PIO0_8/ADC_5)
CAPT_X2: C4.1, U1.16 (PIO0_9/ADC_4)
CAPT_X3: C5.1, U1.15 (PIO0_1/ADC_0/ACMP_I2/TDI/CLKIN)
CAPT_YL: C1.2, U1.24 (PIO0_19/DACOUT)
GND: C6.2, C7.2, J1.3, J1.5, J1.9, J2.2, U1.19 (VSS)
LED0: D1.1 (K), U1.4 (PIO0_13/ADC_10)
LED1: D2.1 (K), U1.3 (PIO0_17/ADC_9)
LED2: D3.1 (K), U1.2 (PIO0_16/ACMP_I4/ADC_3)
LED3: D4.1 (K), U1.1 (PIO0_18)
unnamed: D1.2 (A), RN1.1 (R1.1)
unnamed: D2.2 (A), RN1.2 (R2.1)
unnamed: D3.2 (A), RN1.3 (R3.1)
unnamed: D4.2 (A), RN1.4 (R4.1)
unnamed: J1.2, U1.9 (SWDIO/PIO0_2/TMS)
unnamed: J1.4, U1.8 (SWCLK/PIO0_3/TCK)
unnamed: J1.10, U1.6 (!RESET/PIO0_5)

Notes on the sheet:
Note: KiCAD does not have Cap Touch pad support.

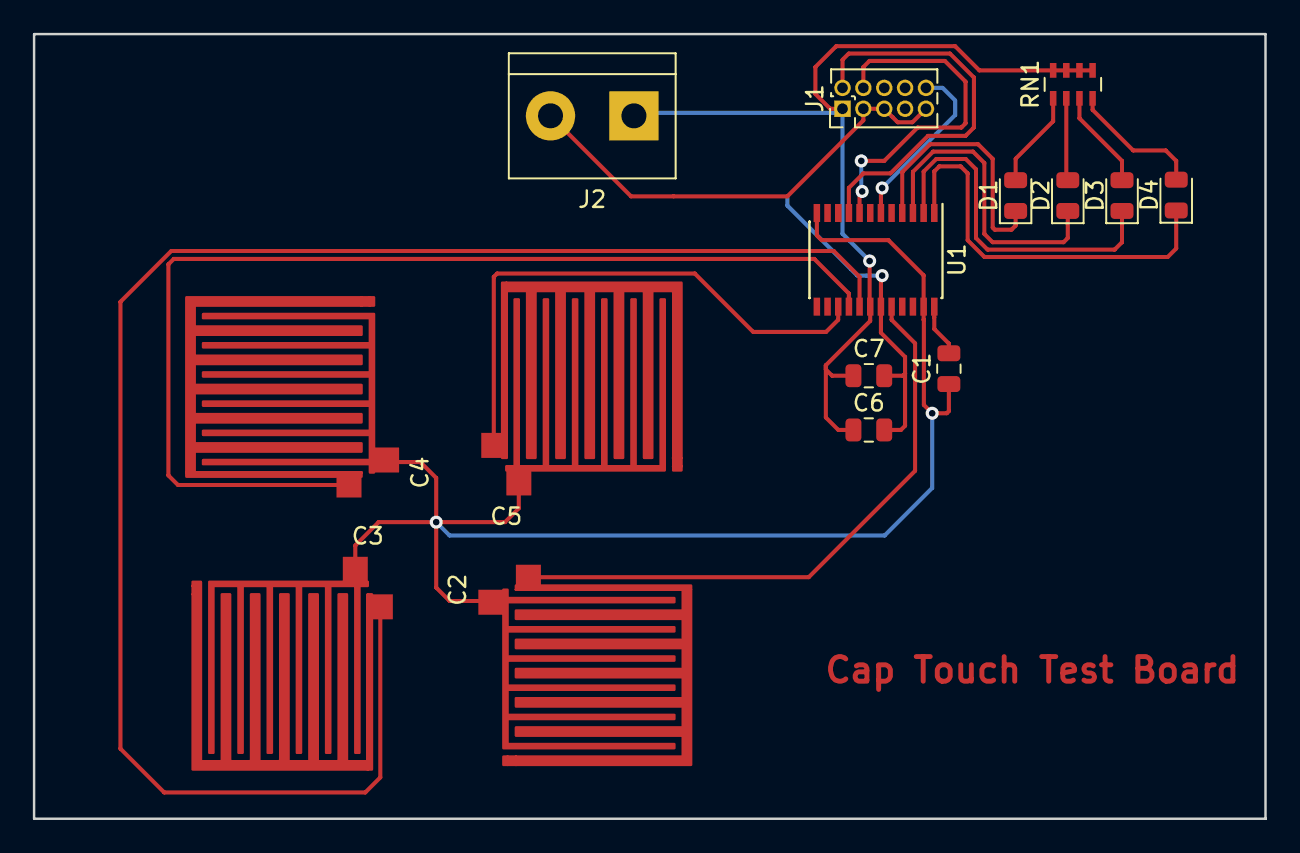
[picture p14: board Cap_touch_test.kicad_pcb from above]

Board: 2 copper layers, 75.0 x 47.8 mm, 15 parts (0 on the bottom side), 19 nets.

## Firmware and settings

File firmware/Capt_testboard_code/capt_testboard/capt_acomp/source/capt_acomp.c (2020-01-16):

/*
 * Copyright 2017 NXP
 * All rights reserved.
 *
 * SPDX-License-Identifier: BSD-3-Clause
 */

#include "board.h"
#include "fsl_capt.h"
#include "fsl_acomp.h"
#include "fsl_debug_console.h"

#include "pin_mux.h"
#include <stdbool.h>
#include "fsl_power.h"
#include "fsl_gpio.h"
/*******************************************************************************
 * Definitions
 ******************************************************************************/
#define DEMO_ACOMP_BASE ACOMP
#define DEMO_ACOMP_CAPT_CHANNEL 4U
#define DEMO_CAPT_BASE CAPT
#define DEMO_CAPT_NOISE 0U
#define DEMO_CAPT_IRQ_NUMBER CMP_CAPT_IRQn
#define DEMO_CAPT_IRQ_HANDLER_FUNC CMP_CAPT_DriverIRQHandler
#define DEMO_CAPT_ENABLE_PINS kCAPT_X0Pin | kCAPT_X1Pin | kCAPT_X2Pin | kCAPT_X3Pin | kCAPT_X4Pin
#define DEMO_CAPT_FILTER_NUM 10U
/*******************************************************************************
 * Prototypes
 ******************************************************************************/
void BOARD_InitLED(void);
void BOARD_LED_ON(uint32_t index);
void BOARD_LED_OFF(void);
static void ACOMP_Configuration(void);
static uint32_t CAPT_DoCalibration(CAPT_Type *base);
/*******************************************************************************
 * Variables
 ******************************************************************************/
uint32_t g_value[16] = {0U};
capt_touch_data_t g_data;
volatile bool g_YesTouchFlag;
/*******************************************************************************
 * Code
 ******************************************************************************/

void BOARD_InitLED(void)
{
    GPIO_PortInit(GPIO, 0U);
    GPIO_PinInit(GPIO, 0U, 20U, &(gpio_pin_config_t){kGPIO_DigitalOutput, 0U});
    GPIO_PinInit(GPIO, 0U, 18U, &(gpio_pin_config_t){kGPIO_DigitalOutput, 0U});
    GPIO_PinInit(GPIO, 0U, 15U, &(gpio_pin_config_t){kGPIO_DigitalOutput, 0U});
    GPIO_PinInit(GPIO, 0U, 8U, &(gpio_pin_config_t){kGPIO_DigitalOutput, 0U});
    GPIO_PinInit(GPIO, 0U, 9U, &(gpio_pin_config_t){kGPIO_DigitalOutput, 0U});
}

void BOARD_LED_ON(uint32_t index)
{
    switch (index)
    {
        case 0U:
            GPIO_PortClear(GPIO, 0U, 1U << 20U);
            break;
        case 1U:
            GPIO_PortClear(GPIO, 0U, 1U << 18U);
            break;
        case 2U:
            GPIO_PortClear(GPIO, 0U, 1U << 15U);
            break;
        case 3U:
            GPIO_PortClear(GPIO, 0U, 1U << 8U);
            break;
        case 4U:
            GPIO_PortClear(GPIO, 0U, 1U << 9U);
            break;
    }
}

void BOARD_LED_OFF(void)
{
    GPIO_PortSet(GPIO, 0U, 1U << 20U);
    GPIO_PortSet(GPIO, 0U, 1U << 18U);
    GPIO_PortSet(GPIO, 0U, 1U << 15U);
    GPIO_PortSet(GPIO, 0U, 1U << 8U);
    GPIO_PortSet(GPIO, 0U, 1U << 9U);
}

/*!
 * @brief ISR for CAPT.
 */
void DEMO_CAPT_IRQ_HANDLER_FUNC(void)
{
    uint32_t n, mask, largest = 0U;
    static uint32_t filter_index;
    static uint8_t largests[DEMO_CAPT_FILTER_NUM];

    CAPT_GetTouchData(DEMO_CAPT_BASE, &g_data);
    g_value[g_data.XpinsIndex] = g_data.count;
    mask                       = CAPT_GetInterruptStatusFlags(DEMO_CAPT_BASE);
    CAPT_ClearInterruptStatusFlags(DEMO_CAPT_BASE, mask);
    if (mask & kCAPT_InterruptOfYesTouchEnable)
    {
        g_YesTouchFlag = true;
    }
    if (mask & kCAPT_InterruptOfPollDoneEnable)
    {
        if (g_YesTouchFlag)
        {
            for (n = 0; n < CAPT_GET_XMAX_NUMBER(DEMO_CAPT_BASE->STATUS); n++)
            {
                if (g_value[n + 1] > g_value[largest])
                {
                    largest = n + 1;
                }
            }
            largests[filter_index++] = largest;
            if (filter_index == DEMO_CAPT_FILTER_NUM)
            {
                filter_index = 0U;
            }
            for (n = 0; n < DEMO_CAPT_FILTER_NUM - 1; n++)
            {
                if (largests[n] != largests[n + 1])
                {
                    g_YesTouchFlag = false;
                    break;
                }
            }
            if (g_YesTouchFlag)
            {
                BOARD_LED_ON(largest);
                g_YesTouchFlag = false;
            }
            else
            {
                BOARD_LED_OFF();
            }
        }
        else
        {
            for (n = 0; n < CAPT_GET_XMAX_NUMBER(DEMO_CAPT_BASE->STATUS); n++)
            {
                largests[n] = n;
            }
            BOARD_LED_OFF();
        }
    }
}

/*!
 * @brief Main function
 */
int main(void)
{
    uint32_t thresold;
    capt_config_t captConfig;

    /* Initialize board hardware. */
    /* Attach 12 MHz clock to USART0 (debug console) */
    CLOCK_Select(BOARD_DEBUG_USART_CLK_ATTACH);

    /* Attach main clock to CAPT */
    CLOCK_Select(kCAPT_Clk_From_Fro);
    POWER_DisablePD(kPDRUNCFG_PD_ACMP);

    BOARD_InitPins();
    BOARD_InitBootClocks();
    BOARD_InitDebugConsole();
    BOARD_InitLED();
    ACOMP_Configuration();

    PRINTF("CAPT ACOMP example.\r\n");

    /* Initialize CAPT module. */
    CAPT_GetDefaultConfig(&captConfig);
    captConfig.triggerMode = kCAPT_ComparatorTriggerMode;
    captConfig.XpinsMode   = kCAPT_InactiveXpinsHighZMode;
    /* Calculate the clock divider to make sure CAPT work in 2Mhz fclk. */
    captConfig.clockDivider = (CLOCK_GetFroFreq() / 2000000U - 1U);
    captConfig.enableXpins  = DEMO_CAPT_ENABLE_PINS;
    CAPT_Init(DEMO_CAPT_BASE, &captConfig);

    /* Do the self-calibration. */
    thresold = CAPT_DoCalibration(DEMO_CAPT_BASE);
    CAPT_SetThreshold(DEMO_CAPT_BASE, thresold - DEMO_CAPT_NOISE);
    PRINTF("Calibration has finished.\r\n");
    BOARD_LED_OFF();
    /* Enable the interrupts. */
    CAPT_EnableInterrupts(DEMO_CAPT_BASE, kCAPT_InterruptOfYesTouchEnable | kCAPT_InterruptOfNoTouchEnable |
                                              kCAPT_InterruptOfPollDoneEnable);
    NVIC_EnableIRQ(DEMO_CAPT_IRQ_NUMBER);

    /* Set polling mode and start poll. */
    CAPT_SetPollMode(DEMO_CAPT_BASE, kCAPT_PollContinuousMode);

    while (1)
    {
    }
}

static void ACOMP_Configuration(void)
{
    acomp_config_t acompConfig;
    acomp_ladder_config_t acompLadderConfig;

    acompConfig.enableSyncToBusClk  = false;
    acompConfig.hysteresisSelection = kACOMP_Hysteresis15MVSelection;
    ACOMP_Init(DEMO_ACOMP_BASE, &acompConfig);

    ACOMP_EnableInterrupts(DEMO_ACOMP_BASE, kACOMP_InterruptsDisable);

    ACOMP_SetInputChannel(DEMO_ACOMP_BASE, DEMO_ACOMP_CAPT_CHANNEL, 0U);

    acompLadderConfig.ladderValue      = 0x10U;
    acompLadderConfig.referenceVoltage = kACOMP_LadderRefVoltagePinVDD;
    ACOMP_SetLadderConfig(DEMO_ACOMP_BASE, &acompLadderConfig);
}

static uint32_t CAPT_DoCalibration(CAPT_Type *base)
{
    uint16_t xpinIndex, repeatCounter;
    uint32_t temp_count, temp_count_high, temp_count_low;
    uint32_t temp_xPins, max_xpins;
    uint32_t average_count[16] = {0U};

    max_xpins  = CAPT_GET_XMAX_NUMBER(CAPT_GetStatusFlags(base));
    temp_xPins = base->CTRL & CAPT_CTRL_XPINSEL_MASK;
    if (base->POLL_TCNT & CAPT_POLL_TCNT_TCHLOW_ER_MASK)
    {
        temp_count = 0xFFFU;
    }
    else
    {
        temp_count = 0U;
    }
    for (xpinIndex = 0U; xpinIndex <= max_xpins; xpinIndex++)
    {
        if (temp_xPins & (1U << (CAPT_CTRL_XPINSEL_SHIFT + xpinIndex)))
        {
            /* Before writing into CTRL register, INCHANGE(bit 15)should equal '0'. */
            while (CAPT_CTRL_INCHANGE_MASK == (CAPT_CTRL_INCHANGE_MASK & base->CTRL))
            {
            }
            base->CTRL = (base->CTRL & ~CAPT_CTRL_XPINSEL_MASK) | 1U << (CAPT_CTRL_XPINSEL_SHIFT + xpinIndex);
            for (repeatCounter = 0U; repeatCounter < 100U; ++repeatCounter)
            {
                /* Before writing into CTRL register, INCHANGE(bit 15)should equal '0'. */
                while (CAPT_CTRL_INCHANGE_MASK == (CAPT_CTRL_INCHANGE_MASK & base->CTRL))
                {
                }
                /* Start poll-now mode. */
                base->CTRL &= ~CAPT_CTRL_POLLMODE_MASK;
                base->CTRL |= CAPT_CTRL_POLLMODE(kCAPT_PollNowMode);
                /* Wait for poll-now done. */
                while (!(base->STATUS & CAPT_STATUS_POLLDONE_MASK))
                {
                }
                /* Clear the status flags. */
                base->STATUS |= base->STATUS;
                average_count[xpinIndex] += ((base->TOUCH & CAPT_TOUCH_COUNT_MASK) >> CAPT_TOUCH_COUNT_SHIFT);
            }
            average_count[xpinIndex] /= 100U;
        }
    }
    /* Restore the xpins. */
    base->CTRL = (base->CTRL & ~CAPT_CTRL_XPINSEL_MASK) | temp_xPins;

    temp_count_high = 0U;
    temp_count_low  = 0xFFFU;
    for (xpinIndex = 0U; xpinIndex <= max_xpins; xpinIndex++)
    {
        if (temp_xPins & (1U << (CAPT_CTRL_XPINSEL_SHIFT + xpinIndex)))
        {
            if (temp_count_high < average_count[xpinIndex])
            {
                temp_count_high = average_count[xpinIndex];
            }
            if (temp_count_low > average_count[xpinIndex])
            {
                temp_count_low = average_count[xpinIndex];
            }
        }
    }
    /* For touchlower mode.*/
    if (base->POLL_TCNT & CAPT_POLL_TCNT_TCHLOW_ER_MASK)
    {
        temp_count = 2 * temp_count_low - temp_count_high;
    }
    else /* For touchhiger mode. */
    {
        temp_count = 2 * temp_count_high - temp_count_low;
    }

    return temp_count;
}

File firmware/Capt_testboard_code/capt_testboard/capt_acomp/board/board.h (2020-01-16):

/*
 * Copyright (c) 2016, Freescale Semiconductor, Inc.
 * Copyright 2016-2018 NXP
 *
 * SPDX-License-Identifier: BSD-3-Clause
 */

#ifndef _BOARD_H_
#define _BOARD_H_

#include "clock_config.h"
#include "fsl_common.h"
#include "fsl_gpio.h"

/*******************************************************************************
 * Definitions
 ******************************************************************************/
/*! @brief The board name */
#define BOARD_NAME "LPCXPRESSO804"

#define BOARD_EXTCLKINRATE (0)

/*! @brief The UART to use for debug messages. */
#define BOARD_DEBUG_USART_TYPE kSerialPort_Uart
#define BOARD_DEBUG_USART_BASEADDR (uint32_t) USART0
#define BOARD_DEBUG_USART_INSTANCE 0U
#define BOARD_DEBUG_USART_CLK_FREQ CLOCK_GetMainClkFreq()
#define BOARD_DEBUG_USART_CLK_ATTACH kUART0_Clk_From_MainClk
#define BOARD_DEBUG_USART_RST kUART0_RST_N_SHIFT_RSTn
#define BOARD_USART_IRQ USART0_IRQn
#define BOARD_USART_IRQ_HANDLER USART0_IRQHandler

#ifndef BOARD_DEBUG_USART_BAUDRATE
#define BOARD_DEBUG_USART_BAUDRATE 9600
#endif /* BOARD_DEBUG_USART_BAUDRATE */

/*! @brief Board led mapping */
#define LOGIC_LED_ON 0U
#define LOGIC_LED_OFF 1U

/* LED_GREEN */
#ifndef BOARD_LED_GREEN_GPIO
#define BOARD_LED_GREEN_GPIO GPIO
#endif
#define BOARD_LED_GREEN_GPIO_PORT 0U
#ifndef BOARD_LED_GREEN_GPIO_PIN
#define BOARD_LED_GREEN_GPIO_PIN 12U
#endif

#define LED_GREEN_INIT(output)                                                              \
    GPIO_PortInit(BOARD_LED_GREEN_GPIO, BOARD_LED_GREEN_GPIO_PORT);                         \
    GPIO_PinInit(BOARD_LED_GREEN_GPIO, BOARD_LED_GREEN_GPIO_PORT, BOARD_LED_GREEN_GPIO_PIN, \
                 &(gpio_pin_config_t){kGPIO_DigitalOutput, (output)}); /*!< Enable target LED_GREEN */
#define LED_GREEN_ON()                                                                       \
    GPIO_PortClear(BOARD_LED_GREEN_GPIO, BOARD_LED_GREEN_GPIO_PORT,                          \
                   1U << BOARD_LED_GREEN_GPIO_PIN) /*!< Turn on target LED_GREEN \ \ \ \ \ \ \
                                                    */
#define LED_GREEN_OFF()                                                                     \
    GPIO_PortSet(BOARD_LED_GREEN_GPIO, BOARD_LED_GREEN_GPIO_PORT,                           \
                 1U << BOARD_LED_GREEN_GPIO_PIN) /*!< Turn off target LED_GREEN \ \ \ \ \ \ \
                                                  */
#define LED_GREEN_TOGGLE()                                           \
    GPIO_PortToggle(BOARD_LED_GREEN_GPIO, BOARD_LED_GREEN_GPIO_PORT, \
                    1U << BOARD_LED_GREEN_GPIO_PIN) /*!< Toggle on target LED_GREEN */

/* LED_BLUE */
#ifndef BOARD_LED_BLUE_GPIO
#define BOARD_LED_BLUE_GPIO GPIO
#endif
#define BOARD_LED_BLUE_GPIO_PORT 0U
#ifndef BOARD_LED_BLUE_GPIO_PIN
#define BOARD_LED_BLUE_GPIO_PIN 11U
#endif

#ifndef BOARD_S1_GPIO
#define BOARD_S1_GPIO GPIO
#endif
#define BOARD_S1_GPIO_PORT 0U
#ifndef BOARD_S1_GPIO_PIN
#define BOARD_S1_GPIO_PIN 13U
#endif
#define BOARD_S1_NAME "S1"
#define BOARD_S1_IRQ PIN_INT0_IRQn
#define BOARD_S1_IRQ_HANDLER PIN_INT0_IRQHandler

#define LED_BLUE_INIT(output)                                                            \
    GPIO_PortInit(BOARD_LED_BLUE_GPIO, BOARD_LED_BLUE_GPIO_PORT);                        \
    GPIO_PinInit(BOARD_LED_BLUE_GPIO, BOARD_LED_BLUE_GPIO_PORT, BOARD_LED_BLUE_GPIO_PIN, \
                 &(gpio_pin_config_t){kGPIO_DigitalOutput, (output)}); /*!< Enable target LED_GREEN */
#define LED_BLUE_ON()                                                                      \
    GPIO_PortClear(BOARD_LED_BLUE_GPIO, BOARD_LED_BLUE_GPIO_PORT,                          \
                   1U << BOARD_LED_BLUE_GPIO_PIN) /*!< Turn on target LED_BLUE \ \ \ \ \ \ \
                                                   */
#define LED_BLUE_OFF()                                                                    \
    GPIO_PortSet(BOARD_LED_BLUE_GPIO, BOARD_LED_BLUE_GPIO_PORT,                           \
                 1U << BOARD_LED_BLUE_GPIO_PIN) /*!< Turn off target LED_BLUE \ \ \ \ \ \ \
                                                 */
#define LED_BLUE_TOGGLE()                                          \
    GPIO_PortToggle(BOARD_LED_BLUE_GPIO, BOARD_LED_BLUE_GPIO_PORT, \
                    1U << BOARD_LED_BLUE_GPIO_PIN) /*!< Toggle on target LED_BLUE */

/* LED_RED */
#ifndef BOARD_LED_RED_GPIO
#define BOARD_LED_RED_GPIO GPIO
#endif
#define BOARD_LED_RED_GPIO_PORT 0U
#ifndef BOARD_LED_RED_GPIO_PIN
#define BOARD_LED_RED_GPIO_PIN 13U
#endif
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

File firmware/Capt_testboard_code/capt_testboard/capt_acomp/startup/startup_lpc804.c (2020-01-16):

//*****************************************************************************
// LPC804 startup code for use with MCUXpresso IDE
//
// Version : 020818
//*****************************************************************************
//
// Copyright 2016-2018 NXP
//
// SPDX-License-Identifier: BSD-3-Clause
//*****************************************************************************

#if defined (DEBUG)
#pragma GCC push_options
#pragma GCC optimize ("Og")
#endif // (DEBUG)

#if defined (__cplusplus)
#ifdef __REDLIB__
#error Redlib does not support C++
#else
//*****************************************************************************
//
// The entry point for the C++ library startup
//
//*****************************************************************************
extern "C" {
    extern void __libc_init_array(void);
}
#endif
#endif

#define WEAK __attribute__ ((weak))
#define WEAK_AV __attribute__ ((weak, section(".after_vectors")))
#define ALIAS(f) __attribute__ ((weak, alias (#f)))

//*****************************************************************************
#if defined (__cplusplus)
extern "C" {
#endif

//*****************************************************************************
// Variable to store CRP value in. Will be placed automatically
// by the linker when "Enable Code Read Protect" selected.
// See crp.h header for more information
//*****************************************************************************
#include <NXP/crp.h>
__CRP const unsigned int CRP_WORD = CRP_NO_CRP ;
//*****************************************************************************
// Declaration of external SystemInit function
//*****************************************************************************
#if defined (__USE_CMSIS)
extern void SystemInit(void);
#endif // (__USE_CMSIS)

//*****************************************************************************
// Patch the AEABI integer divide functions to use MCU's romdivide library
#if defined(__USE_ROMDIVIDE)
// Location in memory that holds the address of the ROM Driver table
#define PTR_ROM_DRIVER_TABLE ((unsigned int *)(0x0F001FF8))
// Variables to store addresses of idiv and udiv functions within MCU ROM
unsigned int *pDivRom_idiv;
unsigned int *pDivRom_uidiv;
#endif

//*****************************************************************************
// Forward declaration of the core exception handlers.
// When the application defines a handler (with the same name), this will
// automatically take precedence over these weak definitions
//*****************************************************************************
     void ResetISR(void);
WEAK void NMI_Handler(void);
WEAK void HardFault_Handler(void);
WEAK void SVC_Handler(void);
WEAK void PendSV_Handler(void);
WEAK void SysTick_Handler(void);
WEAK void IntDefaultHandler(void);

//*****************************************************************************
// Forward declaration of the application IRQ handlers. When the application
// defines a handler (with the same name), this will automatically take
// precedence over weak definitions below
//*****************************************************************************
WEAK void SPI0_IRQHandler(void);
WEAK void Reserved17_IRQHandler(void);
WEAK void DAC0_IRQHandler(void);
WEAK void USART0_IRQHandler(void);
WEAK void USART1_IRQHandler(void);
WEAK void Reserved21_IRQHandler(void);
WEAK void Reserved22_IRQHandler(void);
WEAK void I2C1_IRQHandler(void);
WEAK void I2C0_IRQHandler(void);
WEAK void Reserved25_IRQHandler(void);
WEAK void MRT0_IRQHandler(void);
WEAK void CMP_CAPT_IRQHandler(void);
WEAK void WDT_IRQHandler(void);
WEAK void BOD_IRQHandler(void);
WEAK void FLASH_IRQHandler(void);
WEAK void WKT_IRQHandler(void);
WEAK void ADC_SEQA_IRQHandler(void);
WEAK void ADC_SEQB_IRQHandler(void);
WEAK void ADC_THCMP_IRQHandler(void);
WEAK void ADC_OVR_IRQHandler(void);
WEAK void Reserved36_IRQHandler(void);
WEAK void Reserved37_IRQHandler(void);
WEAK void Reserved38_IRQHandler(void);
WEAK void CTIMER0_IRQHandler(void);
WEAK void PIN_INT0_IRQHandler(void);
WEAK void PIN_INT1_IRQHandler(void);
WEAK void PIN_INT2_IRQHandler(void);
WEAK void PIN_INT3_IRQHandler(void);
WEAK void PIN_INT4_IRQHandler(void);
WEAK void PIN_INT5_IRQHandler(void);
WEAK void PIN_INT6_IRQHandler(void);
WEAK void PIN_INT7_IRQHandler(void);

//*****************************************************************************
// Forward declaration of the driver IRQ handlers. These are aliased
// to the IntDefaultHandler, which is a 'forever' loop. When the driver
// defines a handler (with the same name), this will automatically take
// precedence over these weak definitions
//*****************************************************************************
void SPI0_DriverIRQHandler(void) ALIAS(IntDefaultHandler);
void Reserved17_DriverIRQHandler(void) ALIAS(IntDefaultHandler);
void DAC0_DriverIRQHandler(void) ALIAS(IntDefaultHandler);
void USART0_DriverIRQHandler(void) ALIAS(IntDefaultHandler);
void USART1_DriverIRQHandler(void) ALIAS(IntDefaultHandler);
void Reserved21_DriverIRQHandler(void) ALIAS(IntDefaultHandler);
void Reserved22_DriverIRQHandler(void) ALIAS(IntDefaultHandler);
void I2C1_DriverIRQHandler(void) ALIAS(IntDefaultHandler);
void I2C0_DriverIRQHandler(void) ALIAS(IntDefaultHandler);
void Reserved25_DriverIRQHandler(void) ALIAS(IntDefaultHandler);
void MRT0_DriverIRQHandler(void) ALIAS(IntDefaultHandler);
void CMP_CAPT_DriverIRQHandler(void) ALIAS(IntDefaultHandler);
void WDT_DriverIRQHandler(void) ALIAS(IntDefaultHandler);
void BOD_DriverIRQHandler(void) ALIAS(IntDefaultHandler);
void FLASH_DriverIRQHandler(void) ALIAS(IntDefaultHandler);
void WKT_DriverIRQHandler(void) ALIAS(IntDefaultHandler);
void ADC_SEQA_DriverIRQHandler(void) ALIAS(IntDefaultHandler);
void ADC_SEQB_DriverIRQHandler(void) ALIAS(IntDefaultHandler);
void ADC_THCMP_DriverIRQHandler(void) ALIAS(IntDefaultHandler);
void ADC_OVR_DriverIRQHandler(void) ALIAS(IntDefaultHandler);
void Reserved36_DriverIRQHandler(void) ALIAS(IntDefaultHandler);
void Reserved37_DriverIRQHandler(void) ALIAS(IntDefaultHandler);
void Reserved38_DriverIRQHandler(void) ALIAS(IntDefaultHandler);
void CTIMER0_DriverIRQHandler(void) ALIAS(IntDefaultHandler);
void PIN_INT0_DriverIRQHandler(void) ALIAS(IntDefaultHandler);
void PIN_INT1_DriverIRQHandler(void) ALIAS(IntDefaultHandler);
void PIN_INT2_DriverIRQHandler(void) ALIAS(IntDefaultHandler);
void PIN_INT3_DriverIRQHandler(void) ALIAS(IntDefaultHandler);
void PIN_INT4_DriverIRQHandler(void) ALIAS(IntDefaultHandler);
void PIN_INT5_DriverIRQHandler(void) ALIAS(IntDefaultHandler);
void PIN_INT6_DriverIRQHandler(void) ALIAS(IntDefaultHandler);
void PIN_INT7_DriverIRQHandler(void) ALIAS(IntDefaultHandler);
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

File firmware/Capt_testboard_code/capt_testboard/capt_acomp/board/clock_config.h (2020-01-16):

/*
 * Copyright  2018 NXP
 * All rights reserved.
 *
 *
 * SPDX-License-Identifier: BSD-3-Clause
 */

#ifndef _CLOCK_CONFIG_H_
#define _CLOCK_CONFIG_H_

#include "fsl_common.h"

/*******************************************************************************
 * Definitions
 ******************************************************************************/
#define BOARD_XTAL0_CLK_HZ 12000000U /*!< Board xtal0 frequency in Hz */
#define BOARD_XTAL32K_CLK_HZ 32768U  /*!< Board xtal32K frequency in Hz */

/*******************************************************************************
 ************************ BOARD_InitBootClocks function ************************
 ******************************************************************************/

#if defined(__cplusplus)
extern "C" {
#endif /* __cplusplus*/

/*!
 * @brief This function executes default configuration of clocks.
 *
 */
void BOARD_InitBootClocks(void);

#if defined(__cplusplus)
}
#endif /* __cplusplus*/

/*******************************************************************************
 ******************** Configuration BOARD_BootClockFRO18M **********************
 ******************************************************************************/
/*******************************************************************************
 * Definitions for BOARD_BootClockFRO18M configuration
 ******************************************************************************/
#define BOARD_BOOTCLOCKFRO18M_CORE_CLOCK 9000000U /*!< Core clock frequency: 9000000Hz */

/*******************************************************************************
 * API for BOARD_BootClockFRO18M configuration
 ******************************************************************************/
#if defined(__cplusplus)
extern "C" {
#endif /* __cplusplus*/

/*!
 * @brief This function executes configuration of clocks.
 *
 */
void BOARD_BootClockFRO18M(void);

#if defined(__cplusplus)
}
#endif /* __cplusplus*/

/*******************************************************************************
 ******************** Configuration BOARD_BootClockFRO24M **********************
 ******************************************************************************/
/*******************************************************************************
 * Definitions for BOARD_BootClockFRO24M configuration
 ******************************************************************************/
#define BOARD_BOOTCLOCKFRO24M_CORE_CLOCK 12000000U /*!< Core clock frequency: 12000000Hz */

/*******************************************************************************
 * API for BOARD_BootClockFRO24M configuration
 ******************************************************************************/
#if defined(__cplusplus)
extern "C" {
#endif /* __cplusplus*/

/*!
 * @brief This function executes configuration of clocks.
 *
 */
void BOARD_BootClockFRO24M(void);

#if defined(__cplusplus)
}
#endif /* __cplusplus*/

/*******************************************************************************
 ******************** Configuration BOARD_BootClockFRO30M **********************
 ******************************************************************************/
/*******************************************************************************
 * Definitions for BOARD_BootClockFRO30M configuration
 ******************************************************************************/
#define BOARD_BOOTCLOCKFRO30M_CORE_CLOCK 15000000U /*!< Core clock frequency: 15000000Hz */

/*******************************************************************************
 * API for BOARD_BootClockFRO30M configuration
 ******************************************************************************/
#if defined(__cplusplus)
extern "C" {
#endif /* __cplusplus*/

/*!
 * @brief This function executes configuration of clocks.
 *
 */
void BOARD_BootClockFRO30M(void);

#if defined(__cplusplus)
}
#endif /* __cplusplus*/

#endif /* _CLOCK_CONFIG_H_ */

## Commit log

2019-12-12 Add files via upload
    Local files
    [Clock_idea_outline.FCStd, clock.kicad_pcb, clock.sch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]
2019-12-12 Bare bones of clock schematic made
2019-12-12 Selected to use the LPC804 over the PIC18F45k20
    [clock.sch]
2019-12-13 Selecting serial data lines impressed the importance of selecting appropriate pins for my cap touch
    [clock.sch]
2019-12-14 Selected 596 shift register. Redid LED schematics. Started bom. Updated readme todo list
    [bom.csv, clock.sch]
2019-12-14 Worked on all LED and 596 nets before realizing that I was on the wrong branch. Going to push on branch 191311 and then switch my local back to the master branch
    [clock.sch]
2019-12-17 Decided on a full wave rectifier. Reevaluated the desired transformer and chose a 120 to 12. Reevaluation due to minimum vin on 3v3 rec is 5v3. Added simulations images from QUCS to the build. QUCS u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
    [clock.sch]
2019-12-17 Added QUCS sim files to the project repo
    [clock.sch]
2019-12-17 Correct QUCS sim to adhere more to reality. Noticed incongruity between 596 foot print and default KiCAD schematic symbol.
    [clock.sch]
2019-12-18 Working on placing all 72 castellated holes for the LEDs.
    [clock.kicad_pcb, clock.sch]
2019-12-18 After placing the castellated holes, a problem was discovered with routing. This will require a redesign of the edge layer.
    [clock.kicad_pcb]
2019-12-18 Saving progress on converting outline from 3 x 20 to 4 x 15
    [Clock_idea_outline.FCStd]
2019-12-18 Finished conversion of FreeCAD layout from 3x20 to 4x15
    [Clock_idea_outline.FCStd, clock_outline.dxf]
2019-12-18 Working on moving the castellated holes to the new outline. Saving progress.
    [clock.kicad_pcb, clock.sch]
2019-12-18 Saving progress made on placing parts. Note: concern to routing space. Consider 6/6 rules and think of going up to 5/5 rules
    [clock.kicad_pcb]
2019-12-18 Finished rough part placement. Need to review Transformer. Need to address potential routing issue.
    [clock.kicad_pcb]
2019-12-19 Routing discipline broke down very early. I am going to ride this wave until it is too maddening
    [clock.kicad_pcb, clock.sch]
2019-12-19 Confirmed that current routing plan will not work. TODO re-place the shift registers. Attempt to limit 'roll over'
    [clock.kicad_pcb]
2019-12-19 Converted the 0805 to 0603. Ripped up previous routing
    [clock.kicad_pcb, clock.sch]
2019-12-19 Working on fixing the routing on 6/6 rules. I am worried about power
    [clock.kicad_pcb]
2019-12-20 Finished some layout. 'Rollover' is kicking my butt. May consider using jumpers as a 3rd layer
    [clock.kicad_pcb]
2019-12-21 Saving progress
    [clock.kicad_pcb]
2019-12-21 Saving routing progress
    [clock.kicad_pcb]
2019-12-21 Saving routing progress. 50% done
    [clock.kicad_pcb]
2019-12-22 29/72 LEDs remaining.
    [clock.kicad_pcb]
2019-12-22 Saving progress 191221
    [clock.kicad_pcb]
2019-12-23 ~21 left
    [clock.kicad_pcb]
2019-12-23 Now we are at the hardest LEDs
    [clock.kicad_pcb]
2019-12-23 progress saving
    [clock.kicad_pcb]
2019-12-24 10 LEDs left
    [clock.kicad_pcb]
2019-12-24 2 more collums of LEDs
    [clock.kicad_pcb]
2019-12-27 Ran into a trace width issue. Default kicad trace width is 0.25mm or about 9mils. PCBWay can handle 6 mil space or 0.15mm. So I am reducing the traces down to 6 mils. All of them. I am commiting the 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
    [clock.kicad_pcb]
2019-12-27 Found the automatic setting to update all trace widths.
    [clock.kicad_pcb]
2019-12-27 All LEDs routed. Will consider some optimization e.g. via reduction or shorting traces.
    [clock.kicad_pcb]
2019-12-27 Moving to a new work.
    [clock.kicad_pcb]
2019-12-27 Added Renders
    [clock.kicad_pcb]
2019-12-27 Making proof of concept boards before going too much crazier
    [LED_hole_test.FCStd, LED_hole_test.dxf, Led_tests.kicad_pcb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]
2019-12-27 Completed LED castellated hole test board
    [LED_hole_test.FCStd, LED_hole_test.dxf, Led_tests.kicad_pcb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]
2019-12-27 Generated Gerbers for LED test board. Created proj dir for cap touch test board
    [Cap_touch_test.kicad_pcb, Cap_touch_test.sch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]
2019-12-27 Made schematic for the cap touch test based on the LPC804 app notes
2019-12-27 saving progress.
    [Cap_touch_test.kicad_pcb, Cap_touch_test.sch]
2019-12-28 Complicated pads are beyond my skills at the moment. I will need to create something of 'fill zones'. I reached out some feelers on hackaday but I am proceeding with my current information.
    [Cap_touch_test.kicad_pcb, Cap_touch_test.sch]
2020-01-02 Added test cap touch pads to test board. Added renders. Review before initial submission to PCBway for manufacturing.
    [Cap_touch_test.kicad_pcb, Cap_touch_test.sch]
2020-01-03 Test boards submitted to PCBway for review and approval.
    [Cap_touch_test-B.Cu.gbr, Cap_touch_test-B.Mask.gbr, Cap_touch_test-B.Paste.gbr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]
2020-01-04 addressed error in outline of LED_test board
    [Led_tests-B_Cu.gbr, Led_tests-B_Mask.gbr, Led_tests-B_Paste.gbr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]
2020-01-16 Modified LED section of the code. Will need to read over demo board schema in order to verify pin_mux files
2020-01-18 Converted the process from LPC804 to PIC18F45K20 due to time constraints.
    [clock.kicad_pcb, clock.sch]
2020-01-18 Updated todo list and some tracing
    [clock.kicad_pcb, clock.sch]
2020-01-18 Verified the part selected for shift registers. The part is way off. Updated Schematic. Updating PCB lay out.
    [clock.kicad_pcb, clock.sch]
2020-01-20 Reroute the shift registers
    [clock.kicad_pcb, clock.sch]
2020-01-20 Routing update incomplete.
    [clock.kicad_pcb]
2020-01-20 Need to route power. Considering expanding the board.
    [clock.kicad_pcb, clock.sch]
2020-01-20 TODO: Trace power domains.
    [clock.kicad_pcb, clock.sch]
2020-01-20 2 more traces. Need to add the transformer tabs.
    [clock.kicad_pcb]
2020-01-21 Setup gerbers
    [clock-B.Cu.gbr, clock-B.Mask.gbr, clock-B.Paste.gbr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]
2020-01-21 Gerbers sent to JLCPCB.
